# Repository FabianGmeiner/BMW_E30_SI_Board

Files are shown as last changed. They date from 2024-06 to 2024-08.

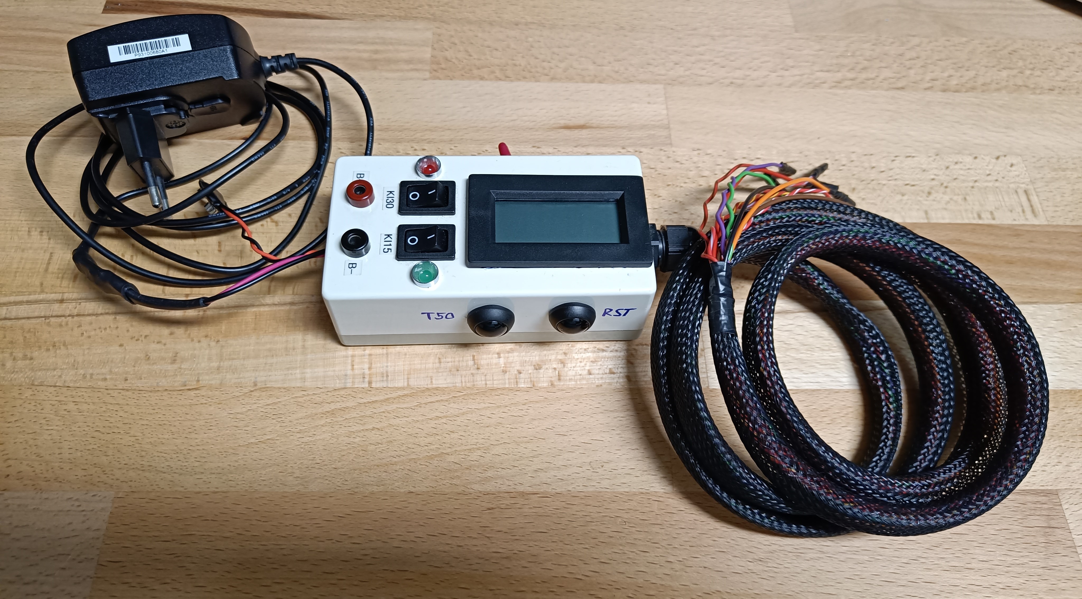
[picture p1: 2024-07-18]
Images/Testing/IMG20240629183347.jpg

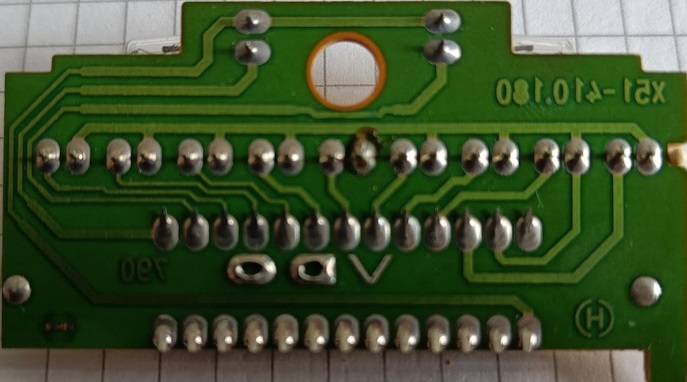
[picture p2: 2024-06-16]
Images/Indicator Rear Crop.jpg

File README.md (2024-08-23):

# About this Project

I'm currently working on a little project for all the early model E30 drivers with SI board trouble from leaky batteries or mechanical damage.

I am reverse engineering the early model SI board, in my case the VDO version (VDO and motometer are interchangeable)

This initial version is a 1:1 copy of the original design. The main microcontroller, the crystal oscillator and the large pin header need to be desoldered and taken over to the new board, but all other components are readily available and stocked parts.

This is mainly to understand the schematics and the workings of the circuit. In a second step I will design my own board with a modern microcontroller and non-volatile storage to work without batteries, with modern and way cheaper components (similar to the board offered by  [ProgRama](https://www.programainc.com/item_detail.aspx?idproduct=177&idcategory=49&sf=)). Also playing with the idea of integrating further functionality, like configurable shift lights on the little indicator board, as all the necessary signals are there anyway.

Warm regards from Germany!

## Current Status

2024/06/24 I received the initial batch of PCBs for testing. This includes the main SI boards as well as the pre-facelift LED board (9 LEDs).

I got all the necessary components from either Mouser or Reichelt (german vendor), but everything is available at Mouser. The [BOM](https://github.com/FabianGmeiner/BMW_E30_SI_Board/blob/main/BOM_SI_Board_Reman.xlsx "BOM_SI_Board_Reman.xlsx") contains all the part descriptions as well as relevant part numbers and the component identification and placement on the second sheet.

The facelift indicator boards (7 LEDs, 3 Bulbs) is based on photographs only, as such I could not yet verify the dimensions apart from measurements from images. 
If anybody has one of those boards laying around and could provide peasurements that would be highly appreciated.

### Testing status

#### Main SI board
**2024/06/24** first board assembled ready for testing.    
**2024/06/30** first functional tests successful. All functions operate as they should, and current consumption is in a nominal range. I am currently building a little pulse generator to test the speed and rpm inputs and test if the oil service lights count down as expected. This will be combined with a long test with the board powered up to check the current consumption and temperatures over longer time. 

| **Test Description** | **Current Draw Board** | **Battery Current** | **Further Comments** |
|---|---|---|---|
| Initial Connection, T30 off, T15 off | | 9.2 µA | Battery current measured between BAT_EN jumper |
| T30 on, T15 off | 3.6 mA | 5.7 µA | All lights stay off, battery current reduces. |
| T30 on, T15 on | 145.9 mA | 5.7 µA | 5 green LEDs turn on, Inspection light turns on |
| Activating T50 (starter signal) | | | Relay clicks, pad indicator lights up |
| Releasing T50 (starter signal) | | | Relay clicks, pad indicator turns off, LEDs turn off |
| Reset Button Pressed | 30.4 mA | | INSP light goes out after ~10s, all lights off |
| T30 on, T15 off | 3.6 mA | | turning ignition off after reset |
| T30 on, T15 on | 89.4 mA | | ignition back on, 5 green LEDs on, INSP light stays off |
| Activating and releasing T50 | 30.5 mA | | Relay cycles, LEDs turn off. All lights off. |
| T30 off, T15 off | | 9.2 µA | |
| Battery charging current | | 22.8 mA | Battery charging with T15 on |
| Battery charging cutoff voltage | | | Board stops charging at a cell voltage of 1.35 V |

The overall functionality, the current consumption as well as the charging current and voltage for the NiMh cells is within the expected range. 

#### Indicator board
**2024/06/24** first board assembled. Electrical test ok. Mechanical fitment is off, the connector header needs to be moved up 2.5mm for the board to sit flush with the main PCB.   
**2024/06/27** PCBs are corrected and updated files uploaded. Ordered a new batch of pre-facelift and facelift boards for testing 
**2024/08/22** noticed during assembly that mounding hole of pre-facelift boards is too small. Needs to be enlarged by 0.5mm -> will be corrected in PCB files
**2024/08/23** updated files for bigger mounting hole

## Schematics

Current versions for the main SI board and the LED indicator board are V2 and can be found as .pdf ([2024_06_15_SI_Board_Schematic_V2.pdf](https://github.com/FabianGmeiner/BMW_E30_SI_Board/blob/main/2024_06_15_SI_Board_Schematic_V2.pdf "2024_06_15_SI_Board_Schematic_V2.pdf"), [2024_06_15_Indicator_Schematic_V2.pdf](https://github.com/FabianGmeiner/BMW_E30_SI_Board/blob/main/2024_06_15_Indicator_Schematic_V2.pdf "2024_06_15_Indicator_Schematic_V2.pdf")) or in the respective KiCad projects.

I also added an LED-only-version of the indicator board, replacing the bulbs with white 5mm LEDs and adding current limiting resistors. The resistors will have to be adapted to the LEDs you are using. 
The same goes for a facelift version of the indicator board, with 7 LEDs (one red) and three bulbs.

The schematics also include the pin assignments and routing of the whole instrument cluster (albeit in german), and should also come in as a handy reference for throubelshooting or repairing an original SI board, e.g. with corroded traces.

## Manufacturing files

Exported Gerbers for getting the boards manufactured are located in the respective KiCad project folders for a variety of different board houses. I ordered mine through JLCPCB. 

## Licensing 
LICENSE NOTE: The root license applies to all subfolders NOT containing their own LICENSE file. If a subfolder contains a different LICENSE file this different license applies to all subfolders below this LICENSE file.

I encourage everyone to get the boards manufactured yourself as the components are cheaply available and its a cool project to keep our old cars running nicely.
If you want to sell any hardware of this project yourself i would kindly ask you to get in contact with me.

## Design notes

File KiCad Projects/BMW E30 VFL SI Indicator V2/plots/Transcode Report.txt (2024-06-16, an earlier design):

   ---- Transcoding 'C:\Users\fabia\OneDrive\Documents\KiCad Projects\BMW E30 VFL SI Indicator\plots\BMW E30 VFL SI Indicator-B_Cu.gbl' ----   Tue Jun  4 21:34:22 2024

D10   --> D144
D11   --> D145
D12   --> D146
D13   --> D147
D14   --> D148
D15   --> D149
D16   --> D150
-----------------------------------------------------------------

   ---- Transcoding 'C:\Users\fabia\OneDrive\Documents\KiCad Projects\BMW E30 VFL SI Indicator\plots\BMW E30 VFL SI Indicator-B_Mask.gbs' ----   Tue Jun  4 21:34:22 2024

D10   --> D151
D11   --> D152
D12   --> D153
D13   --> D154
D14   --> D155
-----------------------------------------------------------------

   ---- Transcoding 'C:\Users\fabia\OneDrive\Documents\KiCad Projects\BMW E30 VFL SI Indicator\plots\BMW E30 VFL SI Indicator-Edge_Cuts.gm1' ----   Tue Jun  4 21:34:22 2024

D10   --> D156
-----------------------------------------------------------------

   ---- Transcoding 'C:\Users\fabia\OneDrive\Documents\KiCad Projects\BMW E30 VFL SI Indicator\plots\BMW E30 VFL SI Indicator-F_Cu.gtl' ----   Tue Jun  4 21:34:22 2024

D10   --> D157
D11   --> D158
D12   --> D159
D13   --> D160
D14   --> D161
D15   --> D162
-----------------------------------------------------------------

   ---- Transcoding 'C:\Users\fabia\OneDrive\Documents\KiCad Projects\BMW E30 VFL SI Indicator\plots\BMW E30 VFL SI Indicator-F_Mask.gts' ----   Tue Jun  4 21:34:22 2024

D10   --> D163
D11   --> D164
D12   --> D165
D13   --> D166
D14   --> D167
-----------------------------------------------------------------

   ---- Transcoding 'C:\Users\fabia\OneDrive\Documents\KiCad Projects\BMW E30 VFL SI Indicator\plots\BMW E30 VFL SI Indicator-F_Silkscreen.gto' ----   Tue Jun  4 21:34:22 2024

D11   --> D168
-----------------------------------------------------------------

   ---- Transcoding 'C:\Users\fabia\OneDrive\Documents\KiCad Projects\BMW E30 VFL SI Indicator\plots\BMW E30 VFL SI Indicator-NPTH.drl' ----   Tue Jun  4 21:34:22 2024

T1   --> T6
-----------------------------------------------------------------

   ---- Transcoding 'C:\Users\fabia\OneDrive\Documents\KiCad Projects\BMW E30 VFL SI Indicator\plots\BMW E30 VFL SI Indicator-NPTH-drl_map.gbr' ----   Tue Jun  4 21:34:22 2024

D10   --> D169
D11   --> D170
D12   --> D171
-----------------------------------------------------------------

   ---- Transcoding 'C:\Users\fabia\OneDrive\Documents\KiCad Projects\BMW E30 VFL SI Indicator\plots\BMW E30 VFL SI Indicator-PTH.drl' ----   Tue Jun  4 21:34:22 2024

T1   --> T7
T2   --> T8
-----------------------------------------------------------------

   ---- Transcoding 'C:\Users\fabia\OneDrive\Documents\KiCad Projects\BMW E30 VFL SI Indicator\plots\BMW E30 VFL SI Indicator-PTH-drl_map.gbr' ----   Tue Jun  4 21:34:22 2024

D10   --> D172
D11   --> D173
D12   --> D174
-----------------------------------------------------------------

   ---- Transcoding 'C:\Users\fabia\OneDrive\Documents\KiCad Projects\BMW E30 VFL SI Indicator\plots\BMW E30 VFL SI Indicator-B_Mask.gbs' ----   Tue Jun  4 21:35:04 2024

D14   --> D100
-----------------------------------------------------------------

   ---- Transcoding 'C:\Users\fabia\OneDrive\Documents\KiCad Projects\BMW E30 VFL SI Indicator\plots\BMW E30 VFL SI Indicator-Edge_Cuts.gm1' ----   Tue Jun  4 21:35:04 2024

D10   --> D101
-----------------------------------------------------------------

   ---- Transcoding 'C:\Users\fabia\OneDrive\Documents\KiCad Projects\BMW E30 VFL SI Indicator\plots\BMW E30 VFL SI Indicator-F_Cu.gtl' ----   Tue Jun  4 21:35:04 2024

D14   --> D102
D15   --> D103
-----------------------------------------------------------------

   ---- Transcoding 'C:\Users\fabia\OneDrive\Documents\KiCad Projects\BMW E30 VFL SI Indicator\plots\BMW E30 VFL SI Indicator-F_Mask.gts' ----   Tue Jun  4 21:35:04 2024

D14   --> D104
-----------------------------------------------------------------

   ---- Transcoding 'C:\Users\fabia\OneDrive\Documents\KiCad Projects\BMW E30 VFL SI Indicator\plots\BMW E30 VFL SI Indicator-F_Silkscreen.gto' ----   Tue Jun  4 21:35:04 2024

D11   --> D105
-----------------------------------------------------------------

   ---- Transcoding 'C:\Users\fabia\OneDrive\Documents\KiCad Projects\BMW E30 VFL SI Indicator\plots\BMW E30 VFL SI Indicator-NPTH-drl_map.gbr' ----   Tue Jun  4 21:35:04 2024

D10   --> D106
D11   --> D107
D12   --> D108
-----------------------------------------------------------------

   ---- Transcoding 'C:\Users\fabia\OneDrive\Documents\KiCad Projects\BMW E30 VFL SI Indicator\plots\BMW E30 VFL SI Indicator-PTH.drl' ----   Tue Jun  4 21:35:04 2024

T1   --> T2
T2   --> T3
-----------------------------------------------------------------

   ---- Transcoding 'C:\Users\fabia\OneDrive\Documents\KiCad Projects\BMW E30 VFL SI Indicator\plots\BMW E30 VFL SI Indicator-PTH-drl_map.gbr' ----   Tue Jun  4 21:35:04 2024

D10   --> D109
D11   --> D110
D12   --> D111
-----------------------------------------------------------------

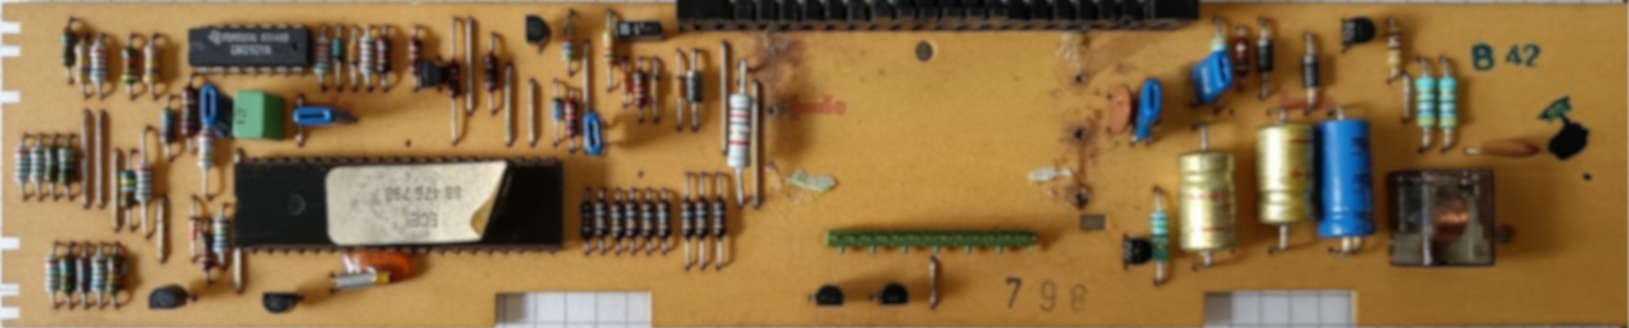
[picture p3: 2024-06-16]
Images/Frontside_Scaled.jpg

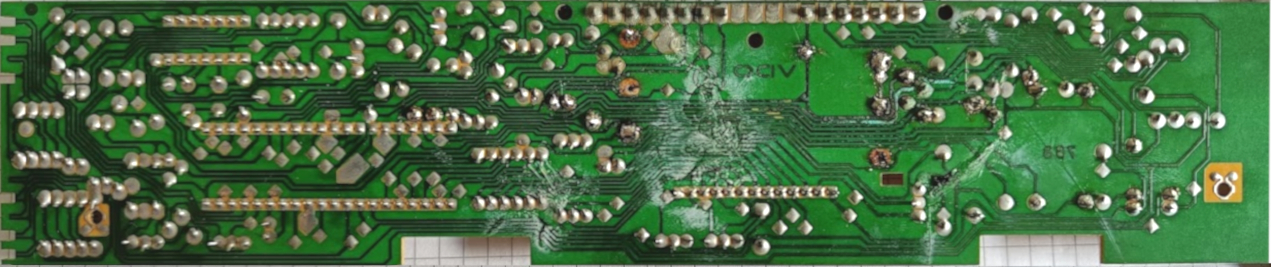
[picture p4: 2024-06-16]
Images/Backside_Scaled.jpg

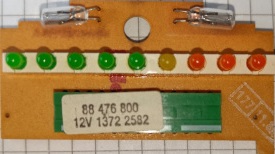
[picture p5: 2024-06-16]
Images/Indicator Front Crop.jpg

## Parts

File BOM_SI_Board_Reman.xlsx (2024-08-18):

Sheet: BOM_V1+V2
 |  |  |  |  |  |  |  |  | SUMME Mouser |  |  | SUMME Reichelt
 |  |  |  |  |  |  |  |  | 6.47 € |  |  | 4.05 €
 | Sum of Qty: | 102
Item # | *Designator | *Qty | Qty. for 10 boards | Description / Value | *Package/Footprint | Type | Your Instructions / Notes | Mouser Nr. | Mouser Unit Price | Mouser Total Price | Reichelt Nr. | Reichelt Unit Price | Reichelt Total Price
1 | R1 | 1 | 10 | 825 Ohms 2% 1/4W | THT |  |  |  |  |  | METALL 825 | 0.035 | 0.035
2 | R2 | 1 | 10 | 1.65k Ohms 1% 1/4W | THT |  |  |  |  |  | METALL 1,65K | 0.035 | 0.035
3 | R3 | 1 | 10 | 3.32k Ohms 2% 50ppm 1/4W | THT |  |  |  |  |  | METALL 3,32K | 0.035 | 0.035
4 | R4 | 1 | 10 | 6.65k Ohms 1% 1/4W | THT |  |  |  |  |  | METALL 6,65K | 0.035 | 0.035
5 | R5 | 1 | 10 | 13.3k Ohms 2% 1/4W | THT |  |  |  |  |  | METALL 13,3K | 0.035 | 0.035
6 | R6 | 1 | 10 | 7.15k Ohms 2% 1/4W | THT |  |  |  |  |  | METALL 7,15K | 0.035 | 0.035
7 | R7 | 1 | 10 | 3.57k Ohms 1% 1/4W | THT |  |  |  |  |  | METALL 3,57K | 0.06 | 0.06
8 | R8 | 1 | 10 | 1.78k Ohms 1% 1/4W | THT |  |  |  |  |  | METALL 1,78K | 0.035 | 0.035
9 | R9 | 1 | 10 | 887 Ohms 1% 1/4W | THT |  |  |  |  |  | METALL 887 | 0.035 | 0.035
10 | R10 | 1 | 10 | 64.9k Ohms 2% 1/4W | THT |  |  |  |  |  | METALL 64,9K | 0.035 | 0.035
11 | R11, R39 | 2 | 10 | 1k Ohms 2% 1/4W | THT |  |  |  |  |  | METALL 1,00K | 0.035 | 0.07
12 | R12 | 1 | 10 | 35.7k Ohms 1% 1/4W | THT |  |  |  |  |  | METALL 35,7K | 0.05 | 0.05
13 | R13, R16 | 2 | 10 | 470k Ohms 5% 1/4W | THT |  |  |  |  |  | METALL 470K | 0.035 | 0.07
14 | R14 | 1 | 10 | 16.2k Ohms 2% 1/4W | THT |  |  |  |  |  | METALL 16,2K | 0.035 | 0.035
15 | R15 | 1 | 10 | 43.2k Ohms 1% 1/4W | THT |  |  |  |  |  | METALL 43,2K | 0.035 | 0.035
16 | R17 | 1 | 10 | 4.75k Ohms 2% 50ppm 1/4W | THT |  |  |  |  |  | METALL 4,75K | 0.035 | 0.035
17 | R18 | 1 | 10 | 750 Ohms 5% 1/2W | THT |  |  | MF1/2CCT52R7500F | 0.406 | 0.406
18 | R19, R40 | 2 | 10 | 51k Ohms 5% 1/4W | THT |  |  |  |  |  | METALL 51,0K | 0.035 | 0.07
19 | R20 | 1 | 10 | 24.9k Ohms 2% 1/4W | THT |  |  |  |  |  | METALL 24,9K | 0.035 | 0.035
20 | R21 | 1 | 10 | 66.5 Ohms 1% 1/4W | THT |  |  |  |  |  | METALL 66,5 | 0.08 | 0.08
21 | R22 | 1 | 10 | 56.2k Ohms 2% 1/4W | THT |  |  |  |  |  | METALL 56,2K | 0.035 | 0.035
22 | R23 | 1 | 10 | 12.1k Ohms 1% 1/4W | THT |  |  |  |  |  | METALL 12,1K | 0.035 | 0.035
23 | R24 | 1 | 10 | 2.7k Ohms 5% 1/4W | THT |  |  |  |  |  | METALL 2,70K | 0.035 | 0.035
24 | R25 | 1 | 10 | 10k Ohms 5% 1/4W | THT |  |  |  |  |  | METALL 10,0K | 0.035 | 0.035
25 | R26, R28 | 2 | 10 | 16k Ohms 5% 1/4W | THT |  |  |  |  |  | METALL 16,0K | 0.035 | 0.07
26 | R27 | 1 | 10 | 75 Ohms 10% 1/4W | THT |  |  |  |  |  | METALL 75,0 | 0.035 | 0.035
27 | R29 | 1 | 10 | 5.6k Ohms 5% 1/4W | THT |  |  |  |  |  | METALL 5,60K | 0.035 | 0.035
28 | R30 - R38 | 9 | 45 | 160 Ohms 5% 1/4W | THT |  |  |  |  |  | METALL 160 | 0.035 | 0.315
29 | R41 | 1 | 10 | 12 Ohms 2% 1W | THT |  |  |  |  |  | VI MBE04140C1209 | 0.17 | 0.17
30 | R42 | 1 | 10 | 75 Ohms 5% 1/2W | THT |  |  | MF1/2DCT52R75R0F | 0.392 | 0.392
31 | R43 | 1 | 10 | 1.3k Ohms 5% 1/4W | THT |  |  |  |  |  | METALL 1,30K | 0.035 | 0.035
32 | R44 | 1 | 10 | 390 Ohms 5% 1/2W | THT |  |  | MF1/2DCT52R3900F | 0.392 | 0.392
33 | R45 | 1 | 10 | 4.7k Ohms 5% 1/4W | THT |  |  |  |  |  | METALL 4,70K | 0.035 | 0.035
34 | R46 | 1 | 10 | 10 Ohms 5% 1/4W | THT |  |  |  |  |  | METALL 10,0 | 0.035 | 0.035
35 | R47, R48 | 2 | 10 | 470 Ohms 5% 1/2W | THT |  |  | MF1/2DCT52R4700F | 0.229 | 0.458
36 | R100 - R113 | 13 | 130 | 0 Ohm wire bridge | THT |  | DNP
37 | D1, D3, D5, D11 | 4 | 20 | 1N4148 | DO-35 |  |  | 512-1N4148 | 0.053 | 0.212
38 | D2 | 1 | 10 | BZX 55C 6V2 500mW | DO-35 |  |  | 78-BZX55C6V2-TAP | 0.101 | 0.101
39 | D4 | 1 | 10 | BZX 55C 5V1 500mW | DO-35 |  |  | 78-BZX55C5V1 | 0.102 | 0.102
40 | D6, D7 | 2 | 10 | BAV21 250mW | DO-35 |  |  |  |  |  | BAV 21 | 0.04 | 0.08
41 | D8, D9, D10 | 3 | 15 | 1N4005G | DO-41 |  |  | 863-1N4005RLG | 0.073 | 0.219
42 | C1, C3, C4, C7, C8 | 5 | 25 | 100nF +50/-20% >=63V | THT, LS=5.08mm | Ceramic MLCC |  | 81-RCER72A104K1M1H3A | 0.179 | 0.895
43 | C2 | 1 | 5 | 470nF 10% 63V MKT1817 | THT, LS=5.08mm | Film |  | MKT1817447065 | 0.755 | 0.755
44 | C5 | 1 | 5 | 100nF 20% 63V MKT1817 | THT, LS=5.08mm | Film |  | MKT1817410065 | 0.429 | 0.429
45 | C6, C12 | 2 | 10 | 4,7nF 10% 1000V | THT, LS=5 / 5.08mm | Ceramic MLCC | RDER73A473K4M1H03A |  |  |  | KERKO-500 4,7N | 0.05 | 0.1
46 | C9, C10 | 2 | 10 | 100µF 20% 16V 85°C | Axial, D < 8,5mm, L< 18mm | Elco | MAL213825101E3 |  |  |  | AX 105 100/16 | 0.43 | 0.86
47 | C11 | 1 | 5 | 100µF 20% 63V 85°C | Axial, D < 8,5mm, L< 18mm | Elco | MAL202138101E3 |  |  |  | COS 105 100/63 | 0.49 | 0.49
48 | Q1, Q4 | 2 | 10 | BC547C 100mA 45V | TO-92 Kinked Lead |  | original: BC237C obsolete |  |  |  | BC 547C | 0.05 | 0.1
49 | Q2 | 1 | 10 | BC557B 100mA 45V | TO-92 Kinked Lead |  | original: BC307B obsolete |  |  |  | BC 557B | 0.05 | 0.05
50 | Q3, Q5, Q6, Q7 | 4 | 20 | BC337-25 800mA 45V | TO-92 Kinked Lead |  |  |  |  |  | BC 337-25 | 0.06 | 0.24
51 | Q8 | 1 | 10 | BC327-16 800mA 45V | TO-92 Kinked Lead |  |  |  |  |  | BC 327-16 | 0.06 | 0.06
52 | K1 | 1 | 10 | SR7-9V-200-1C | THT |  | original: MZ-9HS-C, alternative HKE HRS1KH-S-DC9V, TE OUAZ-SS-109L,900 | 179-SR7-9V-200-1C | 1.01 | 1.01
53 | Y1 | 1 | 10 |  |  |  | no markings |  |  | 0
54 | U1 | 1 | 10 | TE 1-2199299-5 or Amphenol DILB40P-223TLF | DIP-40 |  | take over from original PCB | 571-1-2199299-5 | 0.645 | 0.645
55 | U2 | 1 | 10 | LM2901N | PDIP-14 |  |  | 595-LM2901N | 0.45 | 0.45
56 | BT1, BT2 | 2 | 20 | NiCd Batteries |  |  | https://www.timsclassicparts.nl/de_DE/a-63630636/tacho-zahnradsatz/e30-si-board-akku-grosses-modell/
57 | J1 | 1 | 10 | 19 Pin 3mm Pitch Molded Frame 90° |  |  | take over from original PCB
58 | J2 | 1 | 10 | 13 Pin standard 2,54mm pitch pin header |  |  |  |  |  |  | SL 1X40G 2,54 | 0.27 | 0.27
59 | J3 | 1 | 10 | 2 Pin standard 2,54 pitch pin header |  |  |  |  |  |  | MPE 087-1-002 | 0.06 | 0.06
60 | J4 | 1 | 10 | 2 pin standard 2,54 pitch jumper |  |  |  |  |  |  | JUMPER 2,54 SW | 0.02 | 0.02

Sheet: BOM_V3
 |  |  |  |  |  | Changes compared to V1/V2
 |  |  |  |  |  |  |  |  |  | SUMME Mouser |  |  | SUMME Reichelt
 |  |  |  |  |  |  |  |  |  | 26.00 € |  |  | 4.23 €
 | Sum of Qty: | 91
Item # | *Designator | *Qty | Qty. for 10 boards | Description / Value | *Package/Footprint | Type | Your Instructions / Notes | Pitch [mm] | Mouser Nr. | Mouser Unit Price | Mouser Total Price | Reichelt Nr. | Reichelt Unit Price | Reichelt Total Price
1 | R1 | 1 | 10 | 825 Ohms 2% 1/4W | THT |  |  | 10.16 | 603-MF0207FTE52-825R | 0.112 | 0.112 | METALL 825 | 0.035 | 0.035
2 | R2 | 1 | 10 | 1.65k Ohms 1% 1/4W | THT |  |  | 10.16 | 603-MFR-25FBF52-1K65 | 0.093 | 0.093 | METALL 1,65K | 0.035 | 0.035
3 | R3 | 1 | 10 | 3.32k Ohms 2% 50ppm 1/4W | THT |  |  | 10.16 | 603-MF0207FRE52-3K32 | 0.093 | 0.093 | METALL 3,32K | 0.035 | 0.035
4 | R4 | 1 | 10 | 6.65k Ohms 1% 1/4W | THT |  |  | 10.16 | 603-MF0207FTE52-6K65 | 0.112 | 0.112 | METALL 6,65K | 0.035 | 0.035
5 | R5 | 1 | 10 | 13.3k Ohms 2% 1/4W | THT |  |  | 10.16 | 603-MF0207FTE52-13K3 | 0.112 | 0.112 | METALL 13,3K | 0.035 | 0.035
6 | R6 | 1 | 10 | 7.15k Ohms 2% 1/4W | THT |  |  | 10.16 | 603-MFR-25FRF52-7K15 | 0.093 | 0.093 | METALL 7,15K | 0.035 | 0.035
7 | R7 | 1 | 10 | 3.57k Ohms 1% 1/4W | THT |  |  | 10.16 | 603-MF0207FTE52-3K57 | 0.112 | 0.112 | METALL 3,57K | 0.06 | 0.06
8 | R8 | 1 | 10 | 1.78k Ohms 1% 1/4W | THT |  |  | 10.16 | 603-MFR-25FBF52-1K78 | 0.093 | 0.093 | METALL 1,78K | 0.035 | 0.035
9 | R9 | 1 | 10 | 887 Ohms 1% 1/4W | THT |  |  | 10.16 | 603-MF0207FTE52-887R | 0.112 | 0.112 | METALL 887 | 0.035 | 0.035
10 | R10 | 1 | 10 | 64.9k Ohms 2% 1/4W | THT |  |  | 12.7 | 603-MF0207FTE52-64K9 | 0.112 | 0.112 | METALL 64,9K | 0.035 | 0.035
11 | R11, R39 | 2 | 10 | 1k Ohms 2% 1/4W | THT |  |  | 17,78 / 12,7 | 603-MF0207FRE52-1K | 0.093 | 0.186 | METALL 1,00K | 0.035 | 0.07
12 | R12 | 1 | 10 | 35.7k Ohms 1% 1/4W | THT |  |  | 10.16 | 603-MF0207FTE52-35K7 | 0.112 | 0.112 | METALL 35,7K | 0.05 | 0.05
13 | R13, R16 | 2 | 10 | 470k Ohms 5% 1/4W | THT |  |  | 10.16 | 603-MF0207FRE52-470K | 0.093 | 0.186 | METALL 470K | 0.035 | 0.07
14 | R14 | 1 | 10 | 16.2k Ohms 2% 1/4W | THT |  |  | 10.16 | 603-MF0207FTE52-16K2 | 0.112 | 0.112 | METALL 16,2K | 0.035 | 0.035
15 | R15 | 1 | 10 | 43.2k Ohms 1% 1/4W | THT |  |  | 10.16 | 603-MF0207FTE52-43K2 | 0.112 | 0.112 | METALL 43,2K | 0.035 | 0.035
16 | R17 | 1 | 10 | 4.75k Ohms 2% 50ppm 1/4W | THT |  |  | 10.16 | 603-MF0207FRE52-4K75 | 0.093 | 0.093 | METALL 4,75K | 0.035 | 0.035
17 | R18 | 1 | 10 | 750 Ohms 5% 1/2W | THT |  |  | 12.7 | MF1/2CCT52R7500F | 0.406 | 0.406
18 | R19, R40 | 2 | 10 | 51k Ohms 5% 1/4W | THT |  |  | 10.16 | 603-MF0207FTE52-51K | 0.112 | 0.224 | METALL 51,0K | 0.035 | 0.07
19 | R20 | 1 | 10 | 24.9k Ohms 2% 1/4W | THT |  |  | 15.24 | 603-MF0207FTE52-24K9 | 0.093 | 0.093 | METALL 24,9K | 0.035 | 0.035
20 | R21 | 1 | 10 | 100 Ohms 5% 1/4W | THT |  |  | 10.16 | 603-MF0207FRE52-100R | 0.093 | 0.093 | METALL 100 | 0.035 | 0.035
21 | R22 | 1 | 10 | 56.2k Ohms 2% 1/4W | THT |  |  | 10.16 | 603-MF0207FTE52-56K2 | 0.112 | 0.112 | METALL 56,2K | 0.035 | 0.035
22 | R23 | 1 | 10 | 12.1k Ohms 1% 1/4W | THT |  |  | 10.16 | 603-MF0207FTE52-12K1 | 0.112 | 0.112 | METALL 12,1K | 0.035 | 0.035
23 | R24 | 1 | 10 | 2.7k Ohms 5% 1/4W | THT |  |  | 10.16 | 603-MF0207FRE52-2K7 | 0.093 | 0.093 | METALL 2,70K | 0.035 | 0.035
24 | R25 | 1 | 10 | 10k Ohms 5% 1/4W | THT |  |  | 10.16 | 603-MF0207FRE52-10K | 0.093 | 0.093 | METALL 10,0K | 0.035 | 0.035
25 | R26, R28 | 2 | 10 | 16k Ohms 5% 1/4W | THT |  |  | 20,32 / 10,16 | 603-MF0207FTE52-16K | 0.112 | 0.224 | METALL 16,0K | 0.035 | 0.07
26 | R27 | 1 | 10 | 75 Ohms 10% 1/4W | THT |  |  | 12.7 | 603-MF0207FTE52-75R | 0.112 | 0.112 | METALL 75,0 | 0.035 | 0.035
27 | R29 | 1 | 10 | 5.6k Ohms 5% 1/4W | THT |  |  | 10.16 | 603-MF0207FTE52-5K6 | 0.093 | 0.093 | METALL 5,60K | 0.035 | 0.035
28 | R30 - R38 | 9 | 45 | 160 Ohms 5% 1/4W | THT |  |  | 10,16 / 15,24 | 603-MFR50SFTE52-160R | 0.102 | 0.918 | METALL 160 | 0.035 | 0.315
29 | R41 | 1 | 10 | 12 Ohms 2% 1W | THT |  |  | 22.86 | MBE04140C1209DC100 | 0.595 | 0.595 | VI MBE04140C1209 | 0.17 | 0.17
30 | R42 | 1 | 10 | 75 Ohms 5% 1/2W | THT |  |  | 15.24 | MF1/2DCT52R75R0F | 0.392 | 0.392
31 | R43 | 1 | 10 | 1.3k Ohms 5% 1/4W | THT |  |  | 10.16 | 603-MF0207FTE52-1K3 | 0.112 | 0.112 | METALL 1,30K | 0.035 | 0.035
32 | R44 | 1 | 10 | 390 Ohms 5% 1/2W | THT |  |  | 15.24 | MF1/2DCT52R3900F | 0.392 | 0.392
33 | R45 | 1 | 10 | 4.7k Ohms 5% 1/4W | THT |  |  | 10.16 | 603-MF0207FRE52-4K7 | 0.093 | 0.093 | METALL 4,70K | 0.035 | 0.035
34 | R46 | 1 | 10 | 10 Ohms 5% 1/4W | THT |  |  | 10.16 | 603-MF0207FTE26-10R | 0.093 | 0.093 | METALL 10,0 | 0.035 | 0.035
35 | R47, R48 | 2 | 10 | 470 Ohms 5% 1/2W | THT |  |  | 15.24 | MF1/2DCT52R4700F | 0.229 | 0.458
37 | D1, D3, D5, D11 | 4 | 20 | 1N4148 | DO-35 |  |  | 10,16 / 10,16 / 7,62 / 10,16 | 512-1N4148 | 0.053 | 0.212
38 | D2 | 1 | 10 | BZX 55C 6V2 500mW | DO-35 |  |  | 10.16 | 78-BZX55C6V2-TAP | 0.101 | 0.101
39 | D4 | 1 | 10 | BZX 55C 5V1 500mW | DO-35 |  |  | 10.16 | 78-BZX55C5V1 | 0.102 | 0.102
40 | D6, D7 | 2 | 10 | BAV-21 | DO-35 |  |  | 10,16 / 12,7 | 637-BAV21 | 0.102 | 0.204 | BAV 21 | 0.04 | 0.08
41 | D8, D9, D10 | 3 | 15 | 1N4005G | DO-41 |  |  | 12.7 | 863-1N4005RLG | 0.073 | 0.219
42 | C1, C3, C4, C7, C8 | 5 | 25 | 100nF +50/-20% >=63V | THT, LS=5.08mm | Ceramic MLCC |  | 5.08 | 81-RCER72A104K1M1H3A | 0.179 | 0.895
43 | C2 | 1 | 5 | 470nF 10% 63V MKT1817 | THT, LS=5.08mm | Film |  | 5.08 | MKT1817447065 | 0.755 | 0.755
44 | C5 | 1 | 5 | 100nF 20% 63V MKT1817 | THT, LS=5.08mm | Film |  | 5.08 | MKT1817410065 | 0.429 | 0.429
45 | C6, C12 | 2 | 10 | 4,7nF 10% 1000V | THT, LS=5 / 5.08mm | Ceramic MLCC | RDER73A473K4M1H03A | 5.08 | 81-RDER73A473K4M1H3A | 1.03 | 2.06 | KERKO-500 4,7N | 0.05 | 0.1
46 | C9, C10 | 2 | 10 | 100µF 20% 16V 85°C | Axial, D < 8,5mm, L< 18mm | Elco | MAL213825101E3 | 22.86 | 594-2222-138-35101 | 2.88 | 5.76 | AX 105 100/16 | 0.43 | 0.86
47 | C11 | 1 | 5 | 100µF 20% 63V 85°C | Axial, D < 8,5mm, L< 18mm | Elco | MAL202138101E3 | 22.86 | 594-2222-138-21101 | 2.95 | 2.95 | COS 105 100/63 | 0.49 | 0.49
48 | Q1, Q4 | 2 | 10 | BC547C 100mA 45V | TO-92 Kinked Lead |  | original: BC237C obsolete |  | 637-BC547C | 0.093 | 0.186 | BC 547C | 0.05 | 0.1
50 | Q3, Q5, Q6, Q7 | 4 | 20 | BC337-25 800mA 45V | TO-92 Kinked Lead |  |  |  | 637-BC337-25 | 0.13 | 0.52 | BC 337-25 | 0.06 | 0.24
51 | Q8 | 1 | 10 | BC327-16 800mA 45V | TO-92 Kinked Lead |  |  |  | 637-BC327-16 | 0.13 | 0.13 | BC 327-16 | 0.06 | 0.06
52 | K1 | 1 | 10 | SR7-9V-200-1C | THT |  | original: MZ-9HS-C, alternative HKE HRS1KH-S-DC9V, TE OUAZ-SS-109L,900 |  | 179-SR7-9V-200-1C | 1.01 | 1.01
53 | Y1 | 1 | 10 |  |  |  | take over from original PCB
54 | U1 | 1 | 10 | TE 1-2199299-5 or Amphenol DILB40P-223TLF | DIP-40 |  | take over from original PCB |  | 571-1-2199299-5 | 0.645 | 0.645
55 | U2 | 1 | 10 | LM2901N | PDIP-14 |  |  |  | 595-LM2901N | 0.45 | 0.45
56 | BT1, BT2 | 2 | 20 | Keystone 54 CR123 battery holder |  |  |  |  | 534-54 | 0.623 | 1.246
57 | J1 | 1 | 10 | 19 Pin 3mm Pitch Molded Frame 90° |  |  | take over from original PCB
58 | J2 | 1 | 10 | 13 Pin standard 2,54mm pitch pin header |  |  |  |  | 710-61301311121 | 0.698 | 0.698 | SL 1X40G 2,54 | 0.27 | 0.27
59 | J3 | 1 | 10 | 3 Pin standard 2,54 pitch pin header |  |  |  |  | 649-1012937890304BLF | 0.102 | 0.102 | MPE 087-1-003 | 0.07 | 0.07
61 | D12 | 1 | 10 | BAT46 | DO-35 |  |  | 7.62 | 511-BAT46 | 0.298 | 0.298 | BAT 46 | 0.05 | 0.05
62 | D13 | 1 | 10 | Green LED, 3mm | 3mm LED THT |  |  |  | 710-151031VS06000 | 0.158 | 0.158 | LED 3MM GN | 0.07 | 0.07
63 | C13, C15 | 2 | 20 | 1nF ceramic cap, 5mm pitch THT | THT, LS=5mm |  |  | 5.08 | 594-K102K15X7RH5TH5 | 0.158 | 0.316 | X7R-5 1,0N | 0.08 | 0.16

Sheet: Component Labeling
7.62
10.16
12.7
15.24
17.78
20.32
22.86
25.4

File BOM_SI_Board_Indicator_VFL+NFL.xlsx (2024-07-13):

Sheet: BOM VFL Indicator
 |  |  |  |  |  |  |  | SUMME Reichelt
 |  |  |  |  |  |  |  | 0.99 €
 | Sum of Qty: | 15
Item # | *Designator | *Qty | Description / Value | *Package/Footprint | Type | Reichelt Nr. | Reichelt Unit Price | Reichelt Total Price
1 | PCB | 1 | Manufacturing Files on Github (https://github.com/FabianGmeiner/BMW_E30_SI_Board/tree/main/KiCad%20Projects/BMW%20E30%20VFL%20SI%20Indicator%20LED/gerber_to_order) |  | Custom |  |  | 0
2 | LED Holder | 1 | 3D Files on Github (https://github.com/FabianGmeiner/BMW_E30_SI_Board/blob/main/CAD/LED_Holder_VFL.stp) |  | Custom |  |  | 0
3 | D1-D3 | 3 | Red LED, 3mm, 50mA | 3mm THT |  | LED 3MM RT | 0.07 | 0.21
4 | D4 | 1 | Yellow LED, 3mm, 50mA | 3mm THT |  | LED 3MM GE | 0.07 | 0.07
5 | D5-D9 | 5 | Green LED, 3mm, 50mA | 3mm THT |  | LED 3MM GN | 0.07 | 0.35
6 | D10, D11 | 2 | White LED, rectangular 2x5mm, 250mcd, 20mA | rectangular 2x5mm THT |  | 2534W2D-KHA-A | 0.11 | 0.22
7 | R1, R2 | 2 | 510 Ohms 5% 1/4W | THT |  | METALL 510 | 0.07 | 0.14

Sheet: BOM NFL Indicator
 |  |  |  |  |  |  |  | SUMME Reichelt
 |  |  |  |  |  |  |  | 1.02 €
 | Sum of Qty: | 15
Item # | *Designator | *Qty | Description / Value | *Package/Footprint | Type | Reichelt Nr. | Reichelt Unit Price | Reichelt Total Price
1 | PCB | 1 | Manufacturing Files on Github (https://github.com/FabianGmeiner/BMW_E30_SI_Board/tree/main/KiCad%20Projects/BMW%20E30%20NFL%20SI%20Indicator%20LED/gerber_to_order) |  | Custom
2 | LED Holder | 1 | 3D Files on Github (https://github.com/FabianGmeiner/BMW_E30_SI_Board/blob/main/CAD/LED_Holder_NFL.stp) |  | Custom
3 | D1 | 1 | Red LED, 3mm, 50mA | 3mm THT |  | LED 3MM RT | 0.07 | 0.07
4 | D2 | 1 | Yellow LED, 3mm, 50mA | 3mm THT |  | LED 3MM GE | 0.07 | 0.07
5 | D3-D7 | 5 | Green LED, 3mm, 50mA | 3mm THT |  | LED 3MM GN | 0.07 | 0.35
6 | D10, D12 | 2 | White LED, rectangular 2x5mm, 250mcd, 20mA | rectangular 2x5mm THT |  | 2534W2D-KHA-A | 0.11 | 0.22
7 | D11 | 1 | White LED, 3mm, 20mA | 3mm THT |  | 3034W2D-EHD-A | 0.10 | 0.10
8 | R1-R3 | 3 | 510 Ohms 5% 1/4W | THT |  | METALL 510 | 0.07 | 0.21

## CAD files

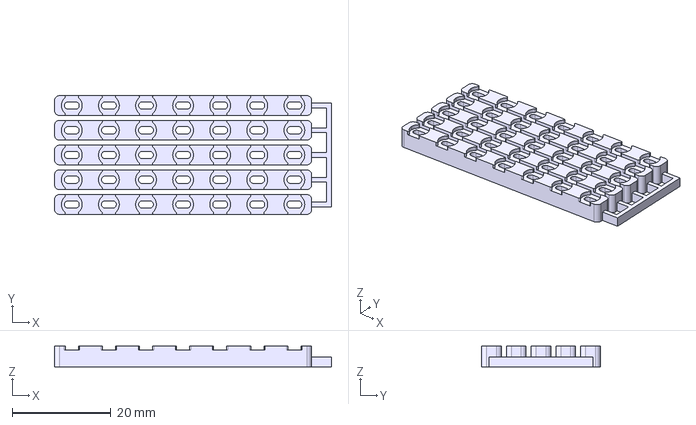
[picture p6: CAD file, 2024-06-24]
CAD/LED_Holder_NFL.stp
56.0 x 24.0 x 4.20 mm

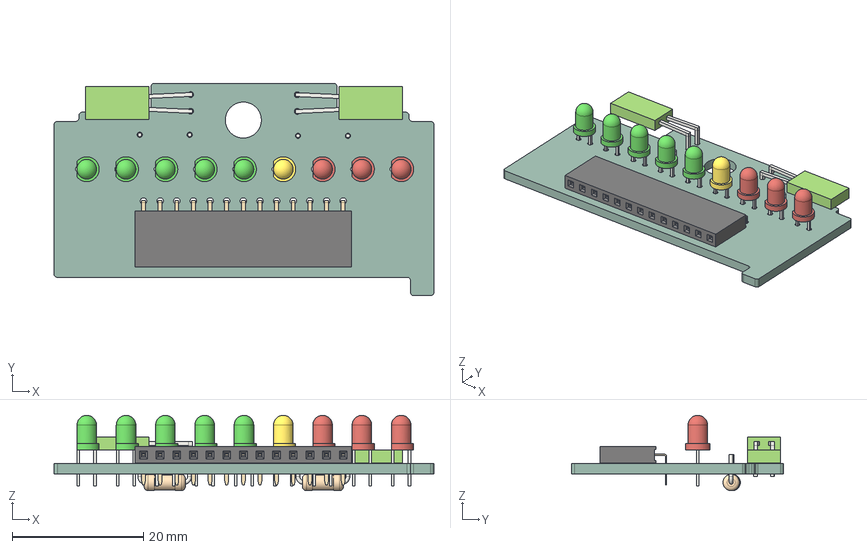
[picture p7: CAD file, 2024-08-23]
KiCad Projects/BMW E30 VFL SI Indicator LED/BMW_E30_VFL_SI_Indicator_LED.step
58.0 x 32.4 x 11.5 mm
LED_D3.0mm x 9
LED_Rectangular_W5.0mm_H2.0mm_Horizontal_O6.35mm_Z3.0mm
LED_Rectangular_W5.0mm_H2.0mm_Horizontal_O6.35mm_Z1.0mm
PinSocket_1x13_P254mm_Horizontal
R_Axial_DIN0207_L63mm_D25mm_P762mm_Horizontal x 2
BMW_E30_VFL_SI_Indicator_LED_PCB

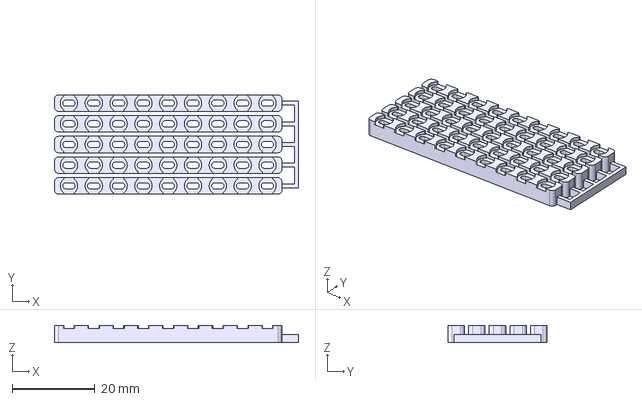
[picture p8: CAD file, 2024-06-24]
CAD/LED_Holder_VFL.stp
59.0 x 24.0 x 4.20 mm

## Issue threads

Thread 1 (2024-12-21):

Request for Information on Power Supply in Testing Images

Anton1001001, 2024-12-21:
Hi Fabian,

I hope you're doing well! I am currently a student working on developing electronic PCBs, and I have a particular interest in classic German cars, especially BMW E30. I noticed the power supply featured in the BMW_E30_SI_Board\Images\Testing folder, and I was wondering if you could tell me the name or model of that power supply?

I would really appreciate your help, and I’m excited to learn more about your work in this area.

Best regards,
Anton

FabianGmeiner, 2024-12-22:
Hi Anton,

the power supply box you can see on the images is a pretty rudimentary perfboard job on the inside.
The main power supply is a generic AC to 24V DC Power supply i had lying around.

I then used two of these small adjustable DCDC boards (something like this: https://www.amazon.de/Heevhas-Spannungsregler-Step-Down-Leistungswandlermodul-Einstellbare-Stromversorgungsmodul/dp/B0CW9MGLZ2/) for the 12V and 5V supplies.

On the 12V side, I added two switches to be able to supply the T30 and T15 pin separately. I also added a small ampmeter (something like this: https://www.conrad.de/de/p/voltcraft-dvm210-digitales-einbaumessgeraet-199-9-mv-beliebig-erweiterbar-durch-vorschalten-von-widerstaenden-126596.html) in the 12V path to monitor the current consumption.

I also added a button to switch the reset input pin to 5V to reset the board, and a button to switch T50 (starter signal) to 12V to test if the lights go out correctly after starting the car.

Since I just threw all that together I dont have any schematics or similar, but I hope the description helps

Anton1001001, 2024-12-25:
Thank you so much for your detailed explanation and the links! This is really helpful. I'll take some time to go through everything and try to assemble the power supply myself. Your description has given me a much better understanding of how to approach it.

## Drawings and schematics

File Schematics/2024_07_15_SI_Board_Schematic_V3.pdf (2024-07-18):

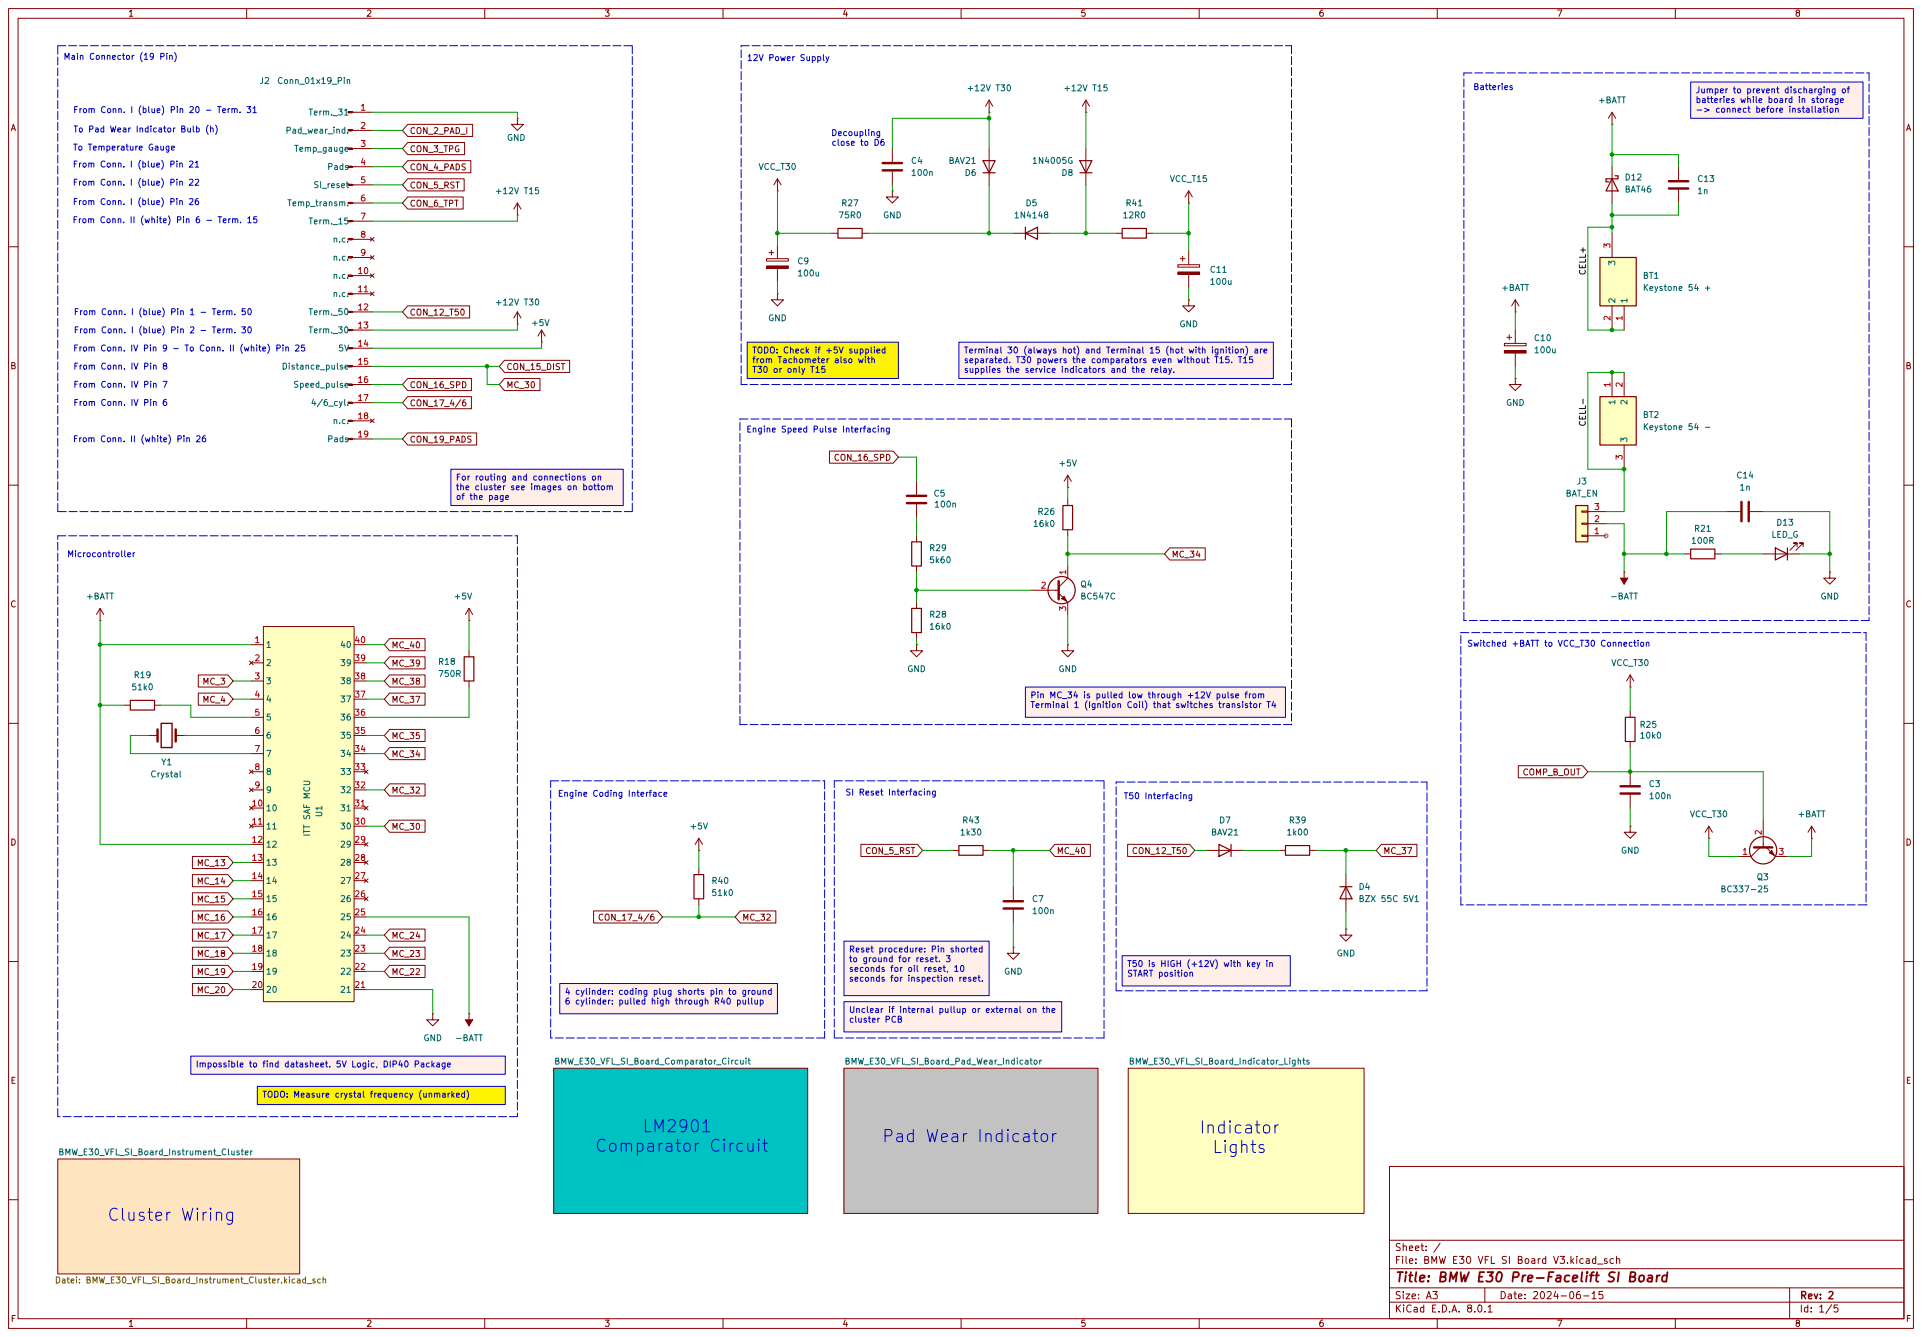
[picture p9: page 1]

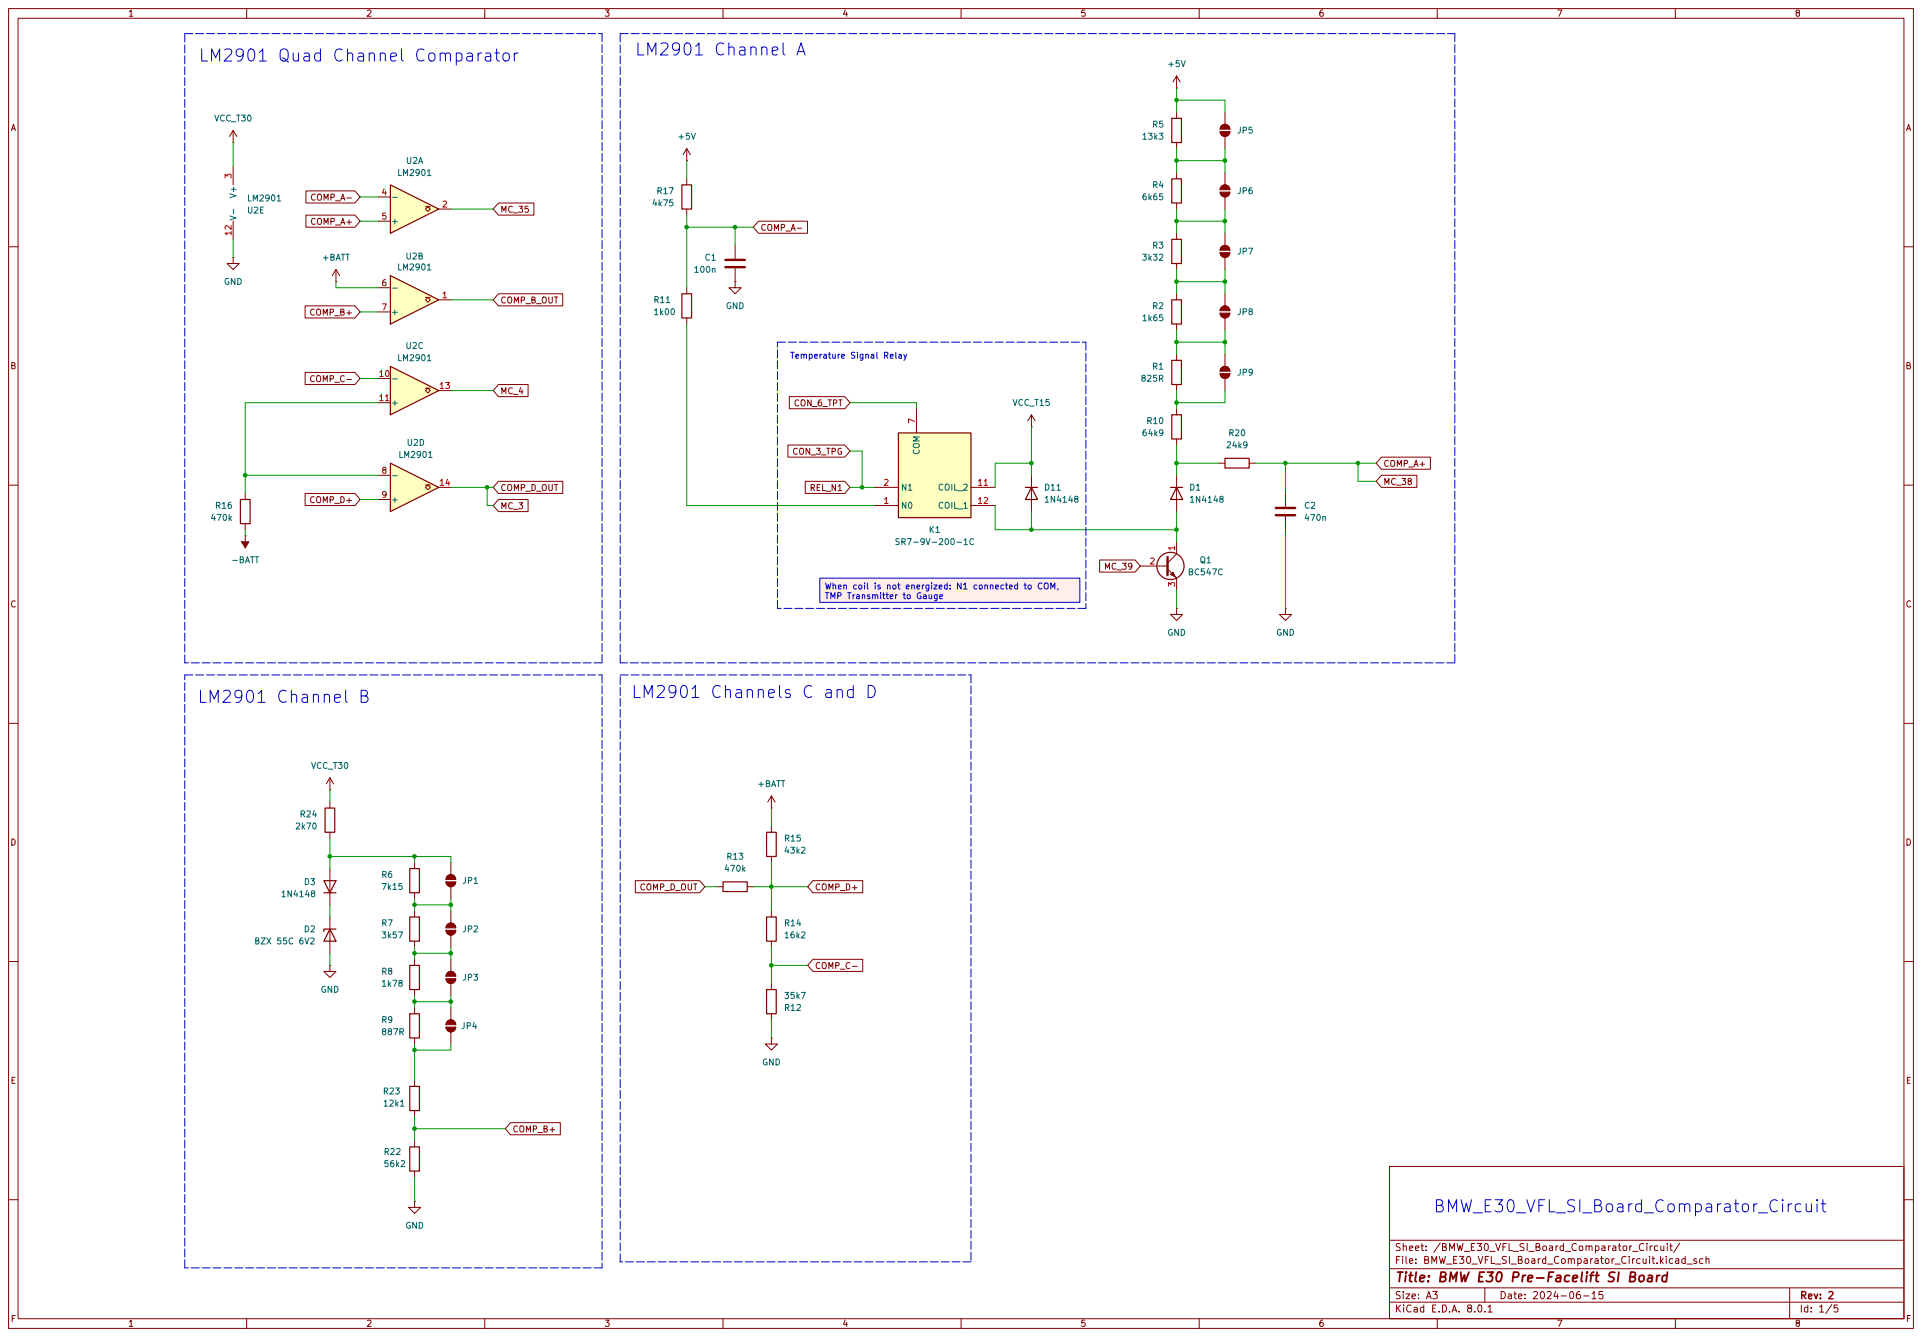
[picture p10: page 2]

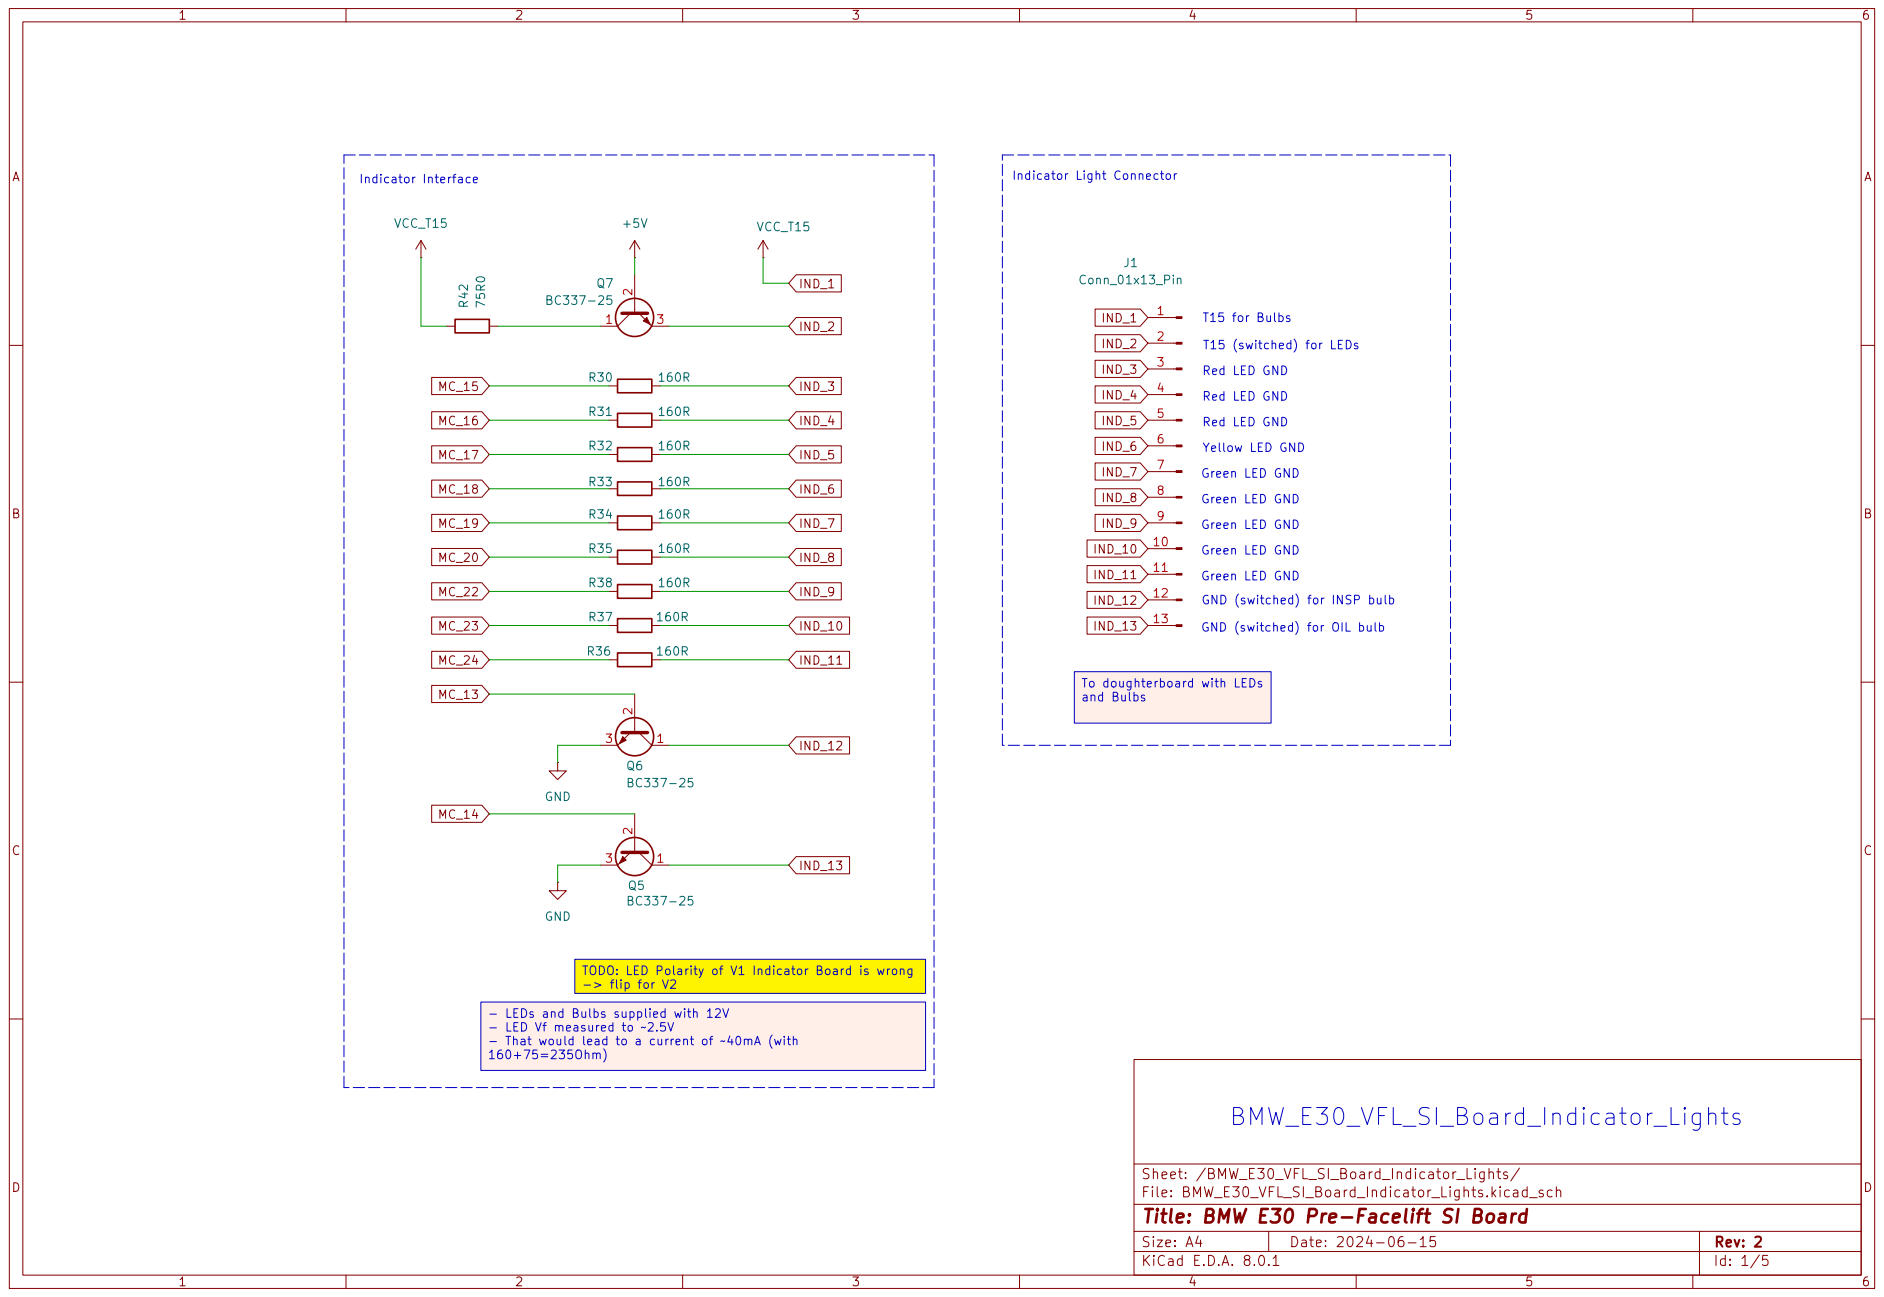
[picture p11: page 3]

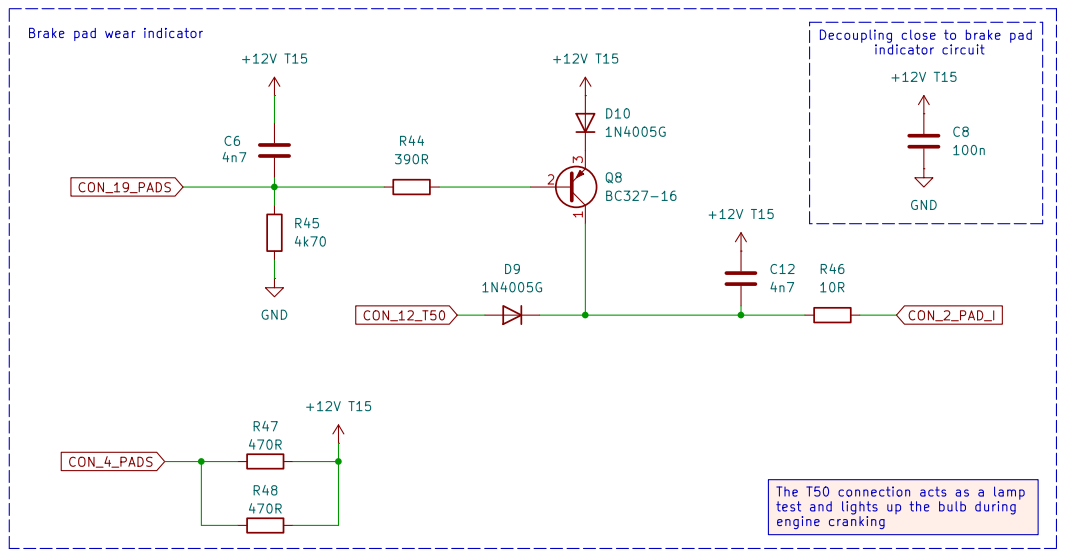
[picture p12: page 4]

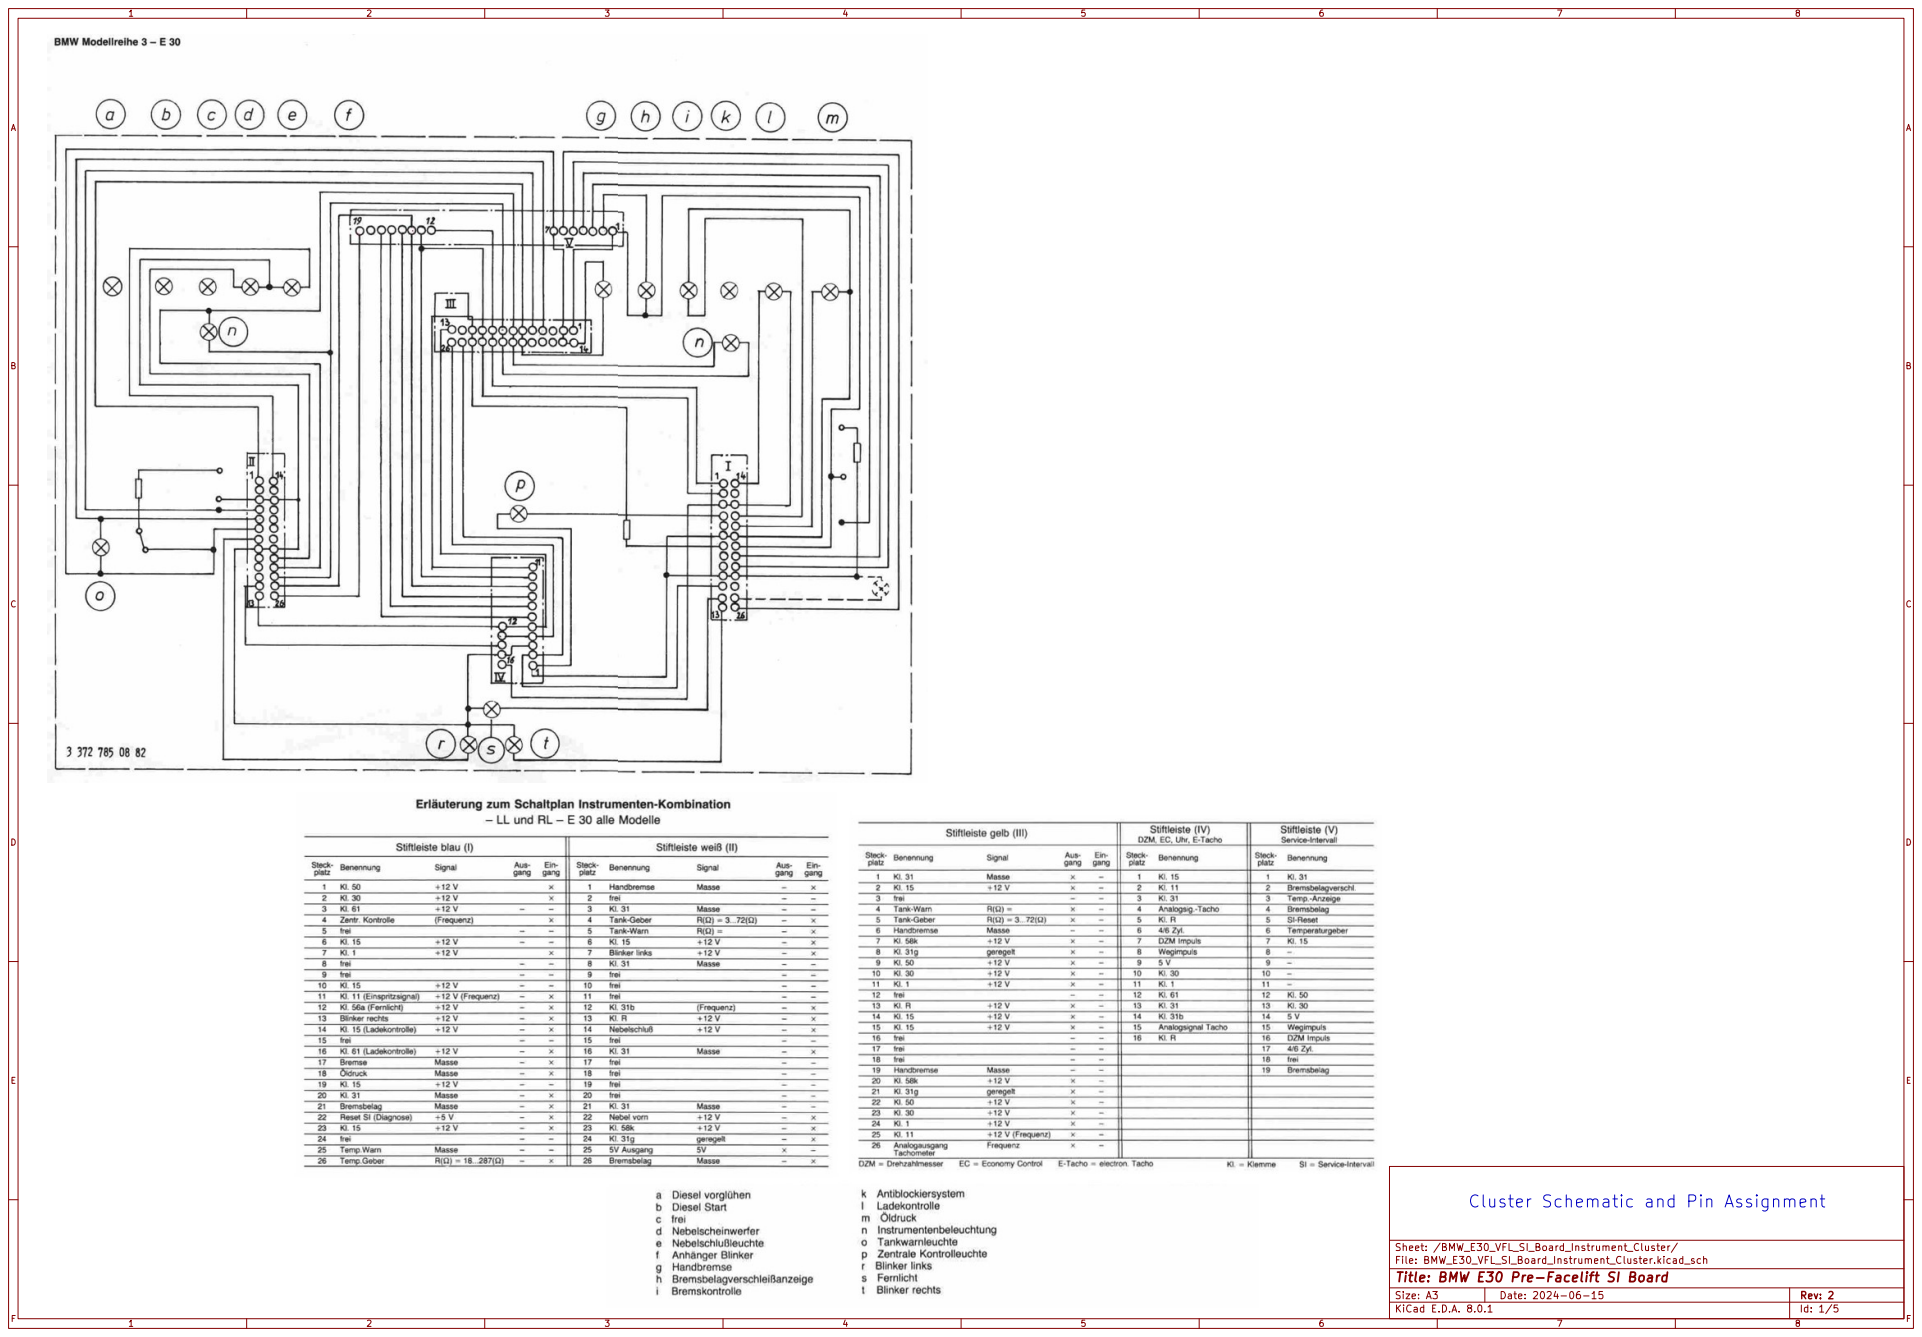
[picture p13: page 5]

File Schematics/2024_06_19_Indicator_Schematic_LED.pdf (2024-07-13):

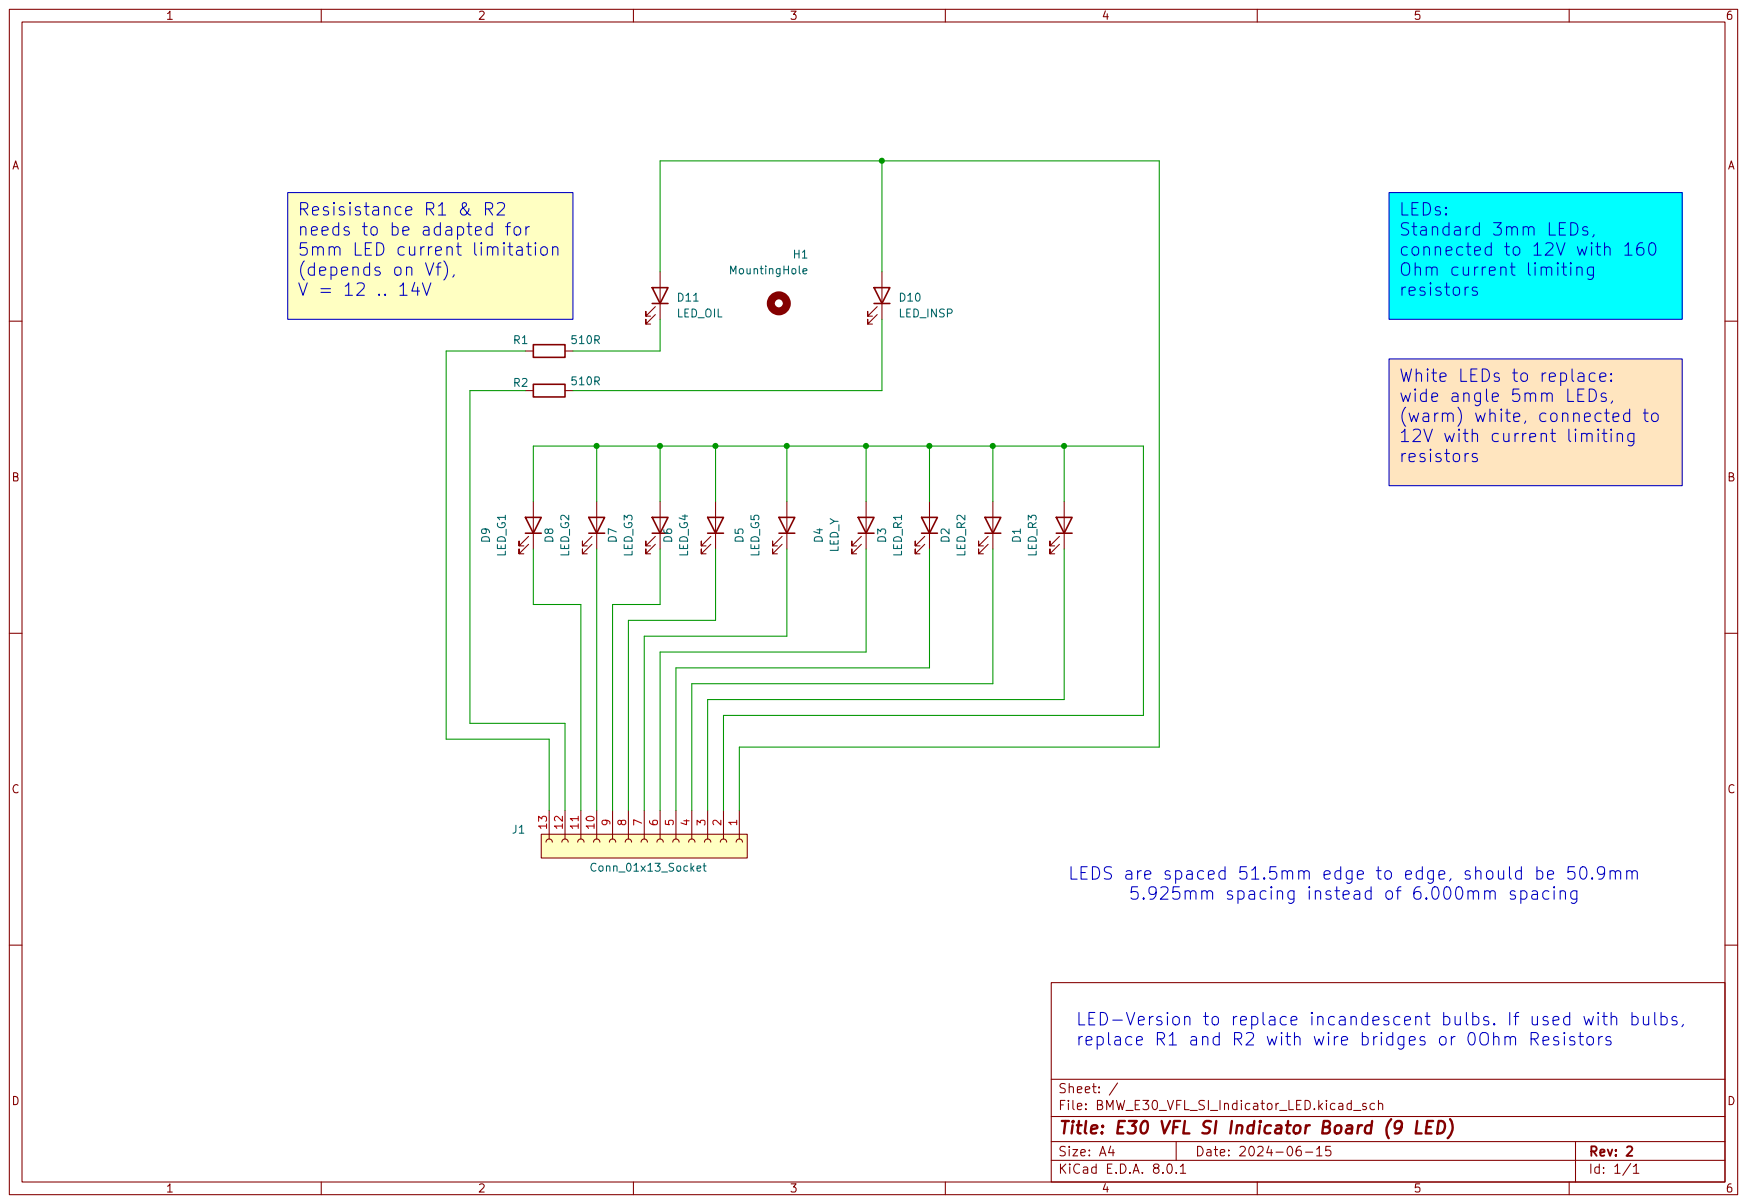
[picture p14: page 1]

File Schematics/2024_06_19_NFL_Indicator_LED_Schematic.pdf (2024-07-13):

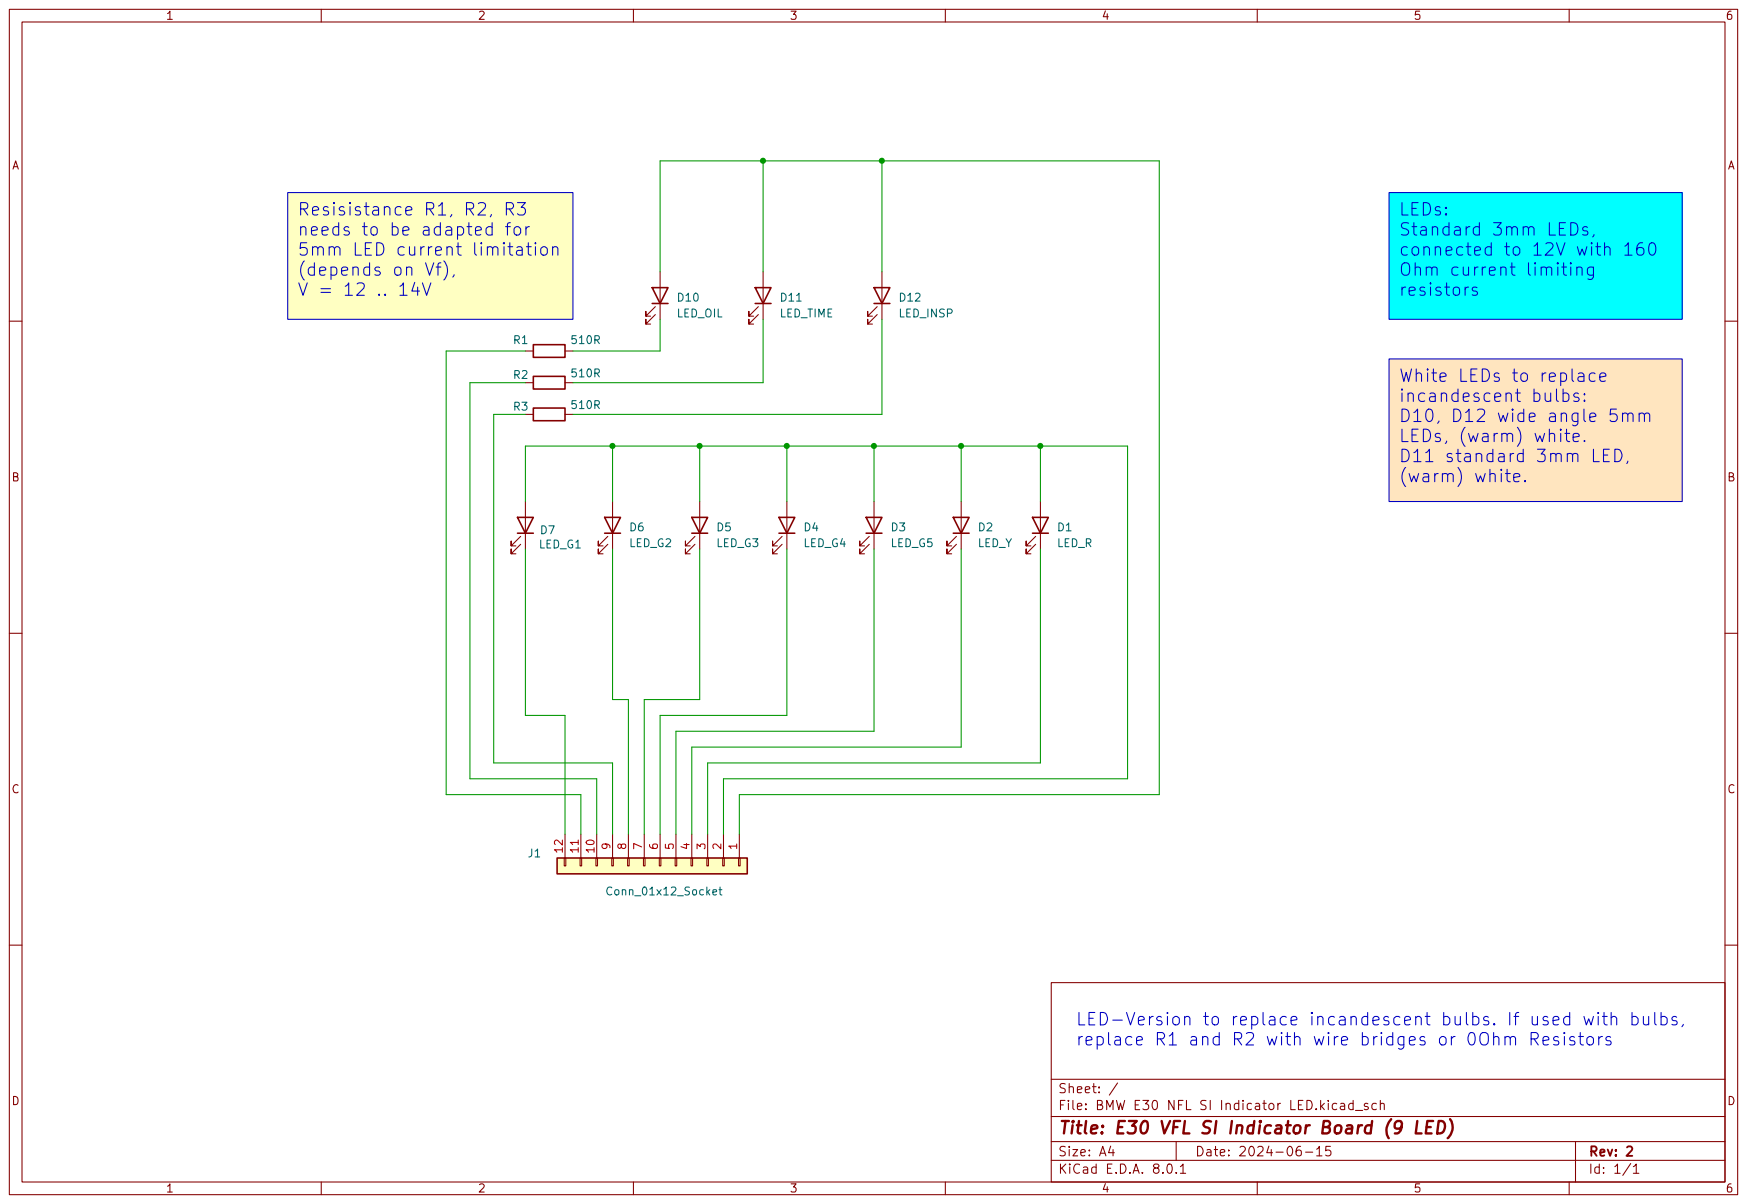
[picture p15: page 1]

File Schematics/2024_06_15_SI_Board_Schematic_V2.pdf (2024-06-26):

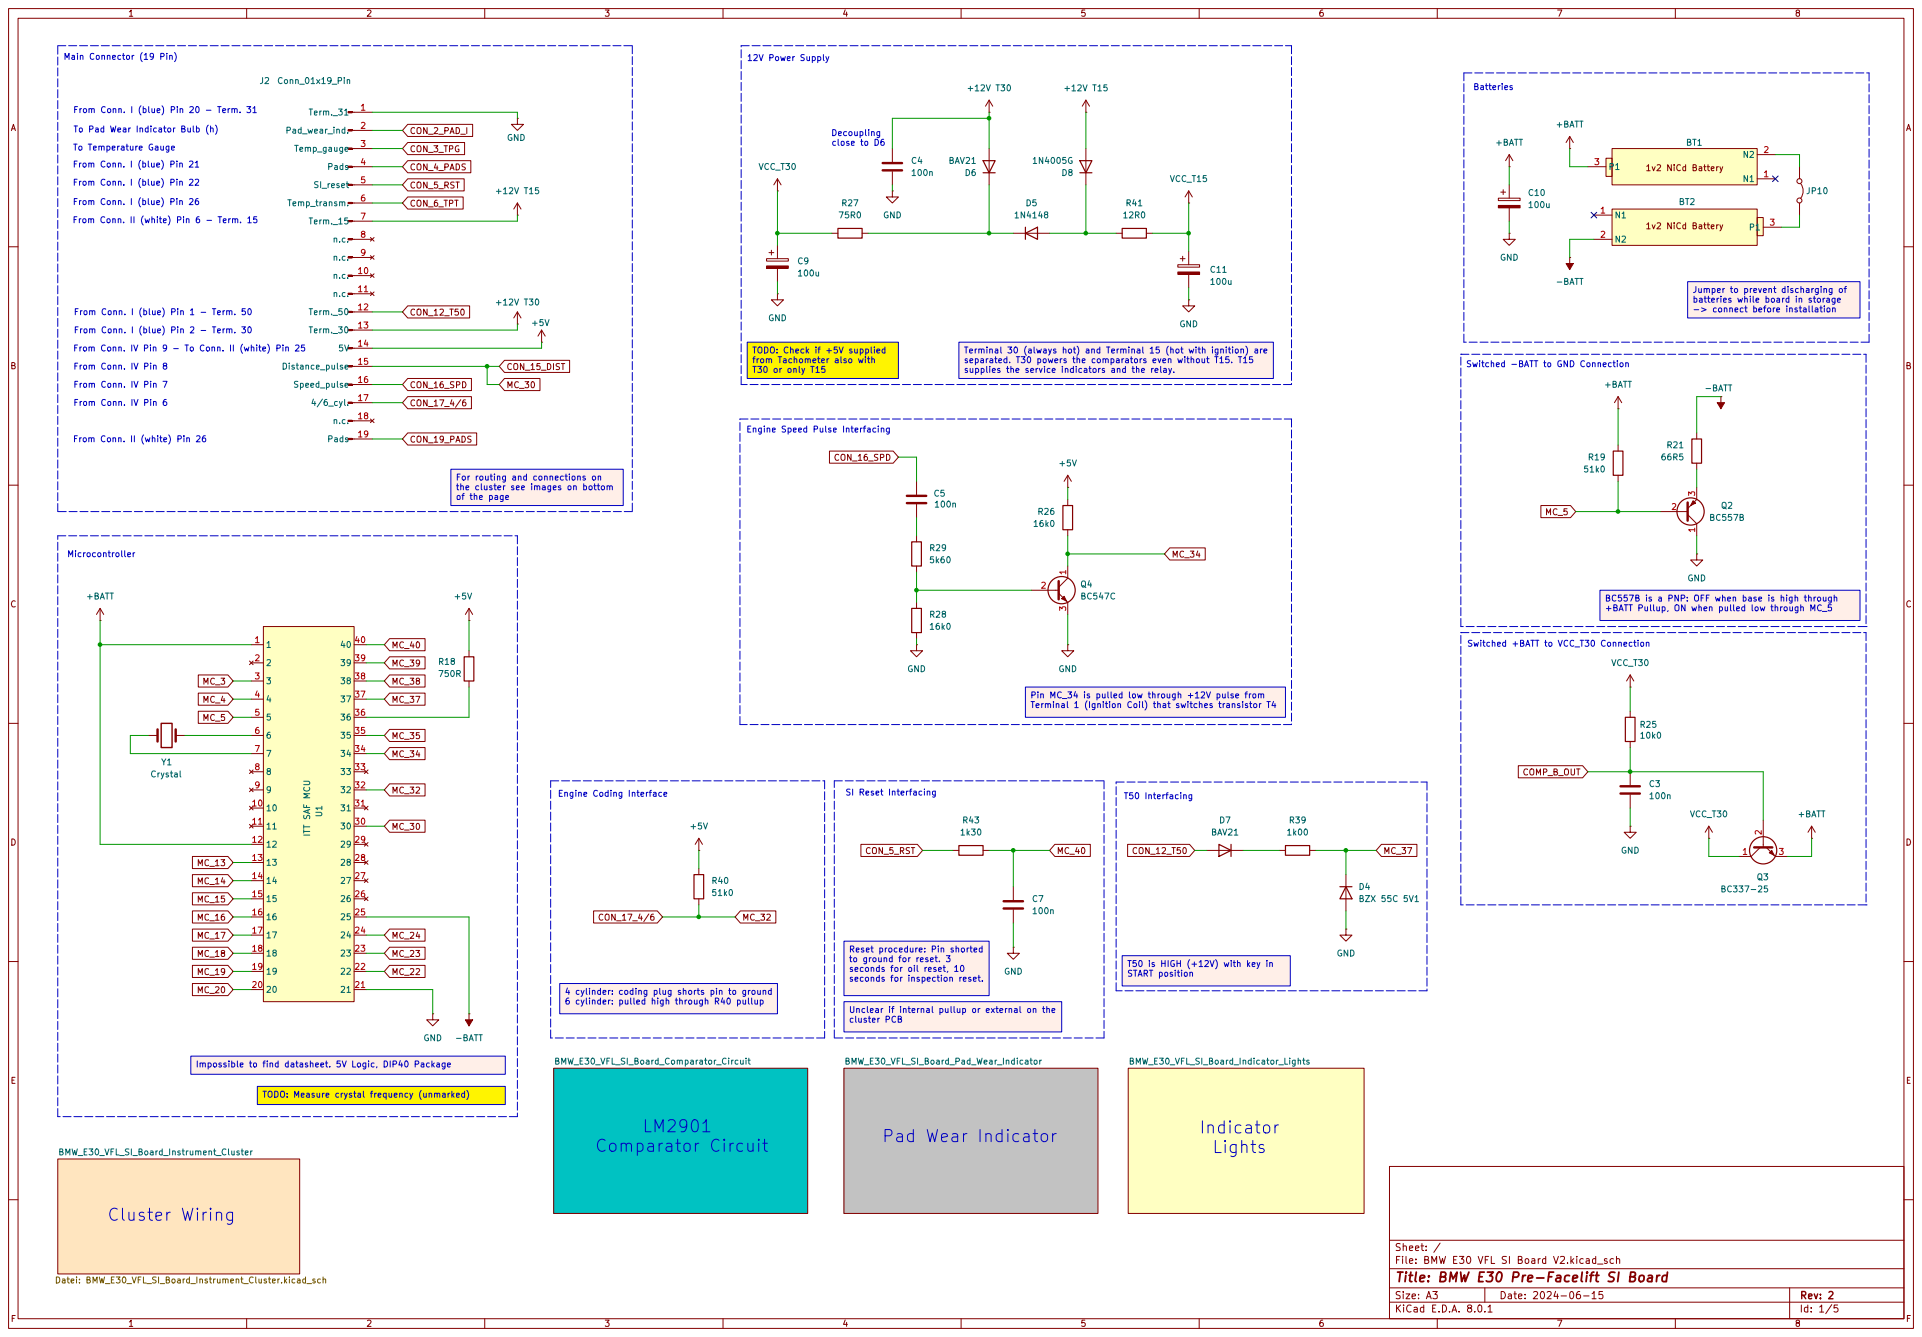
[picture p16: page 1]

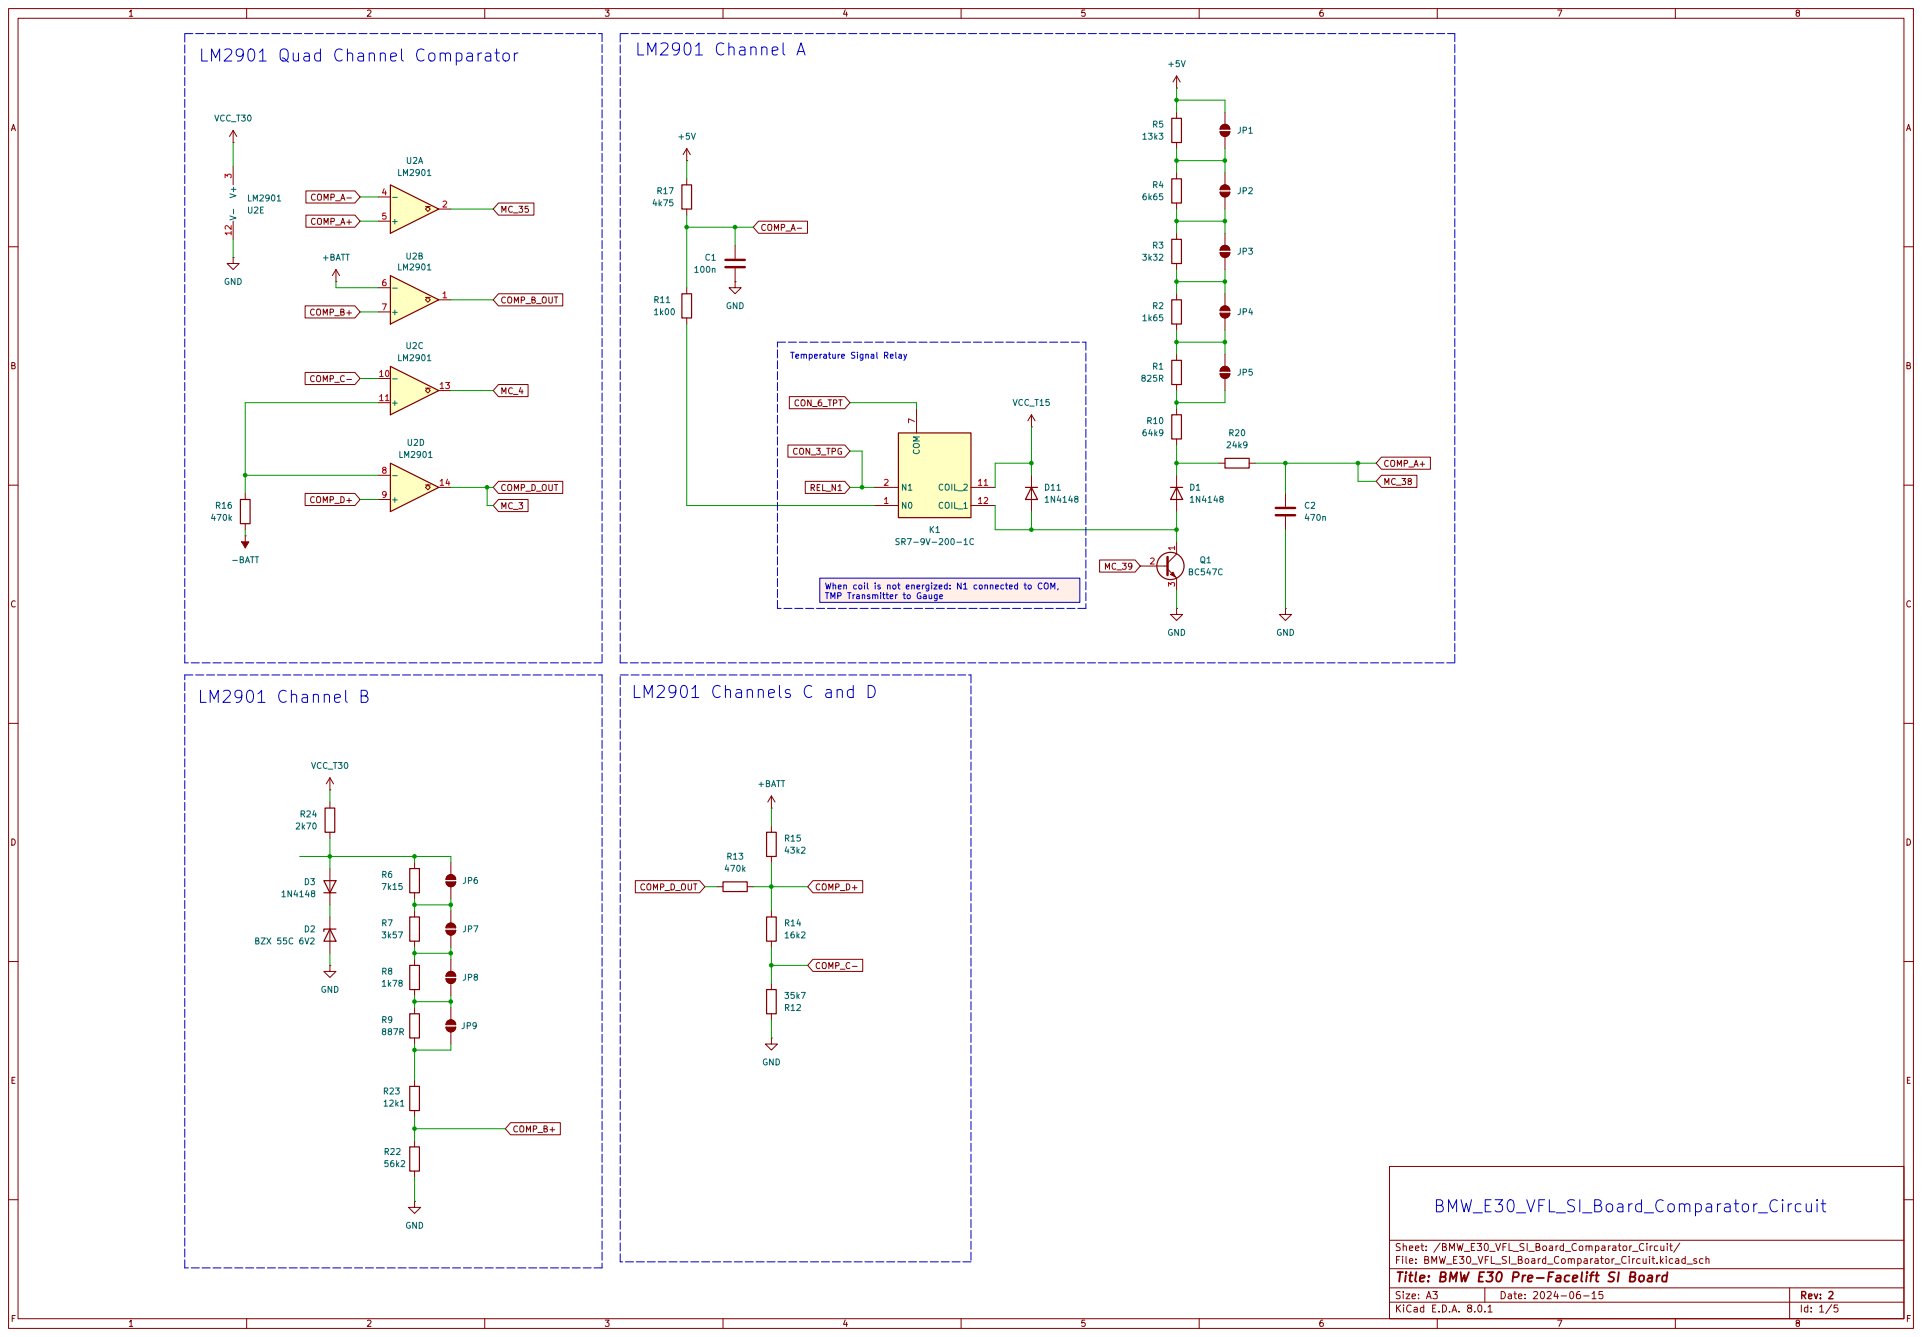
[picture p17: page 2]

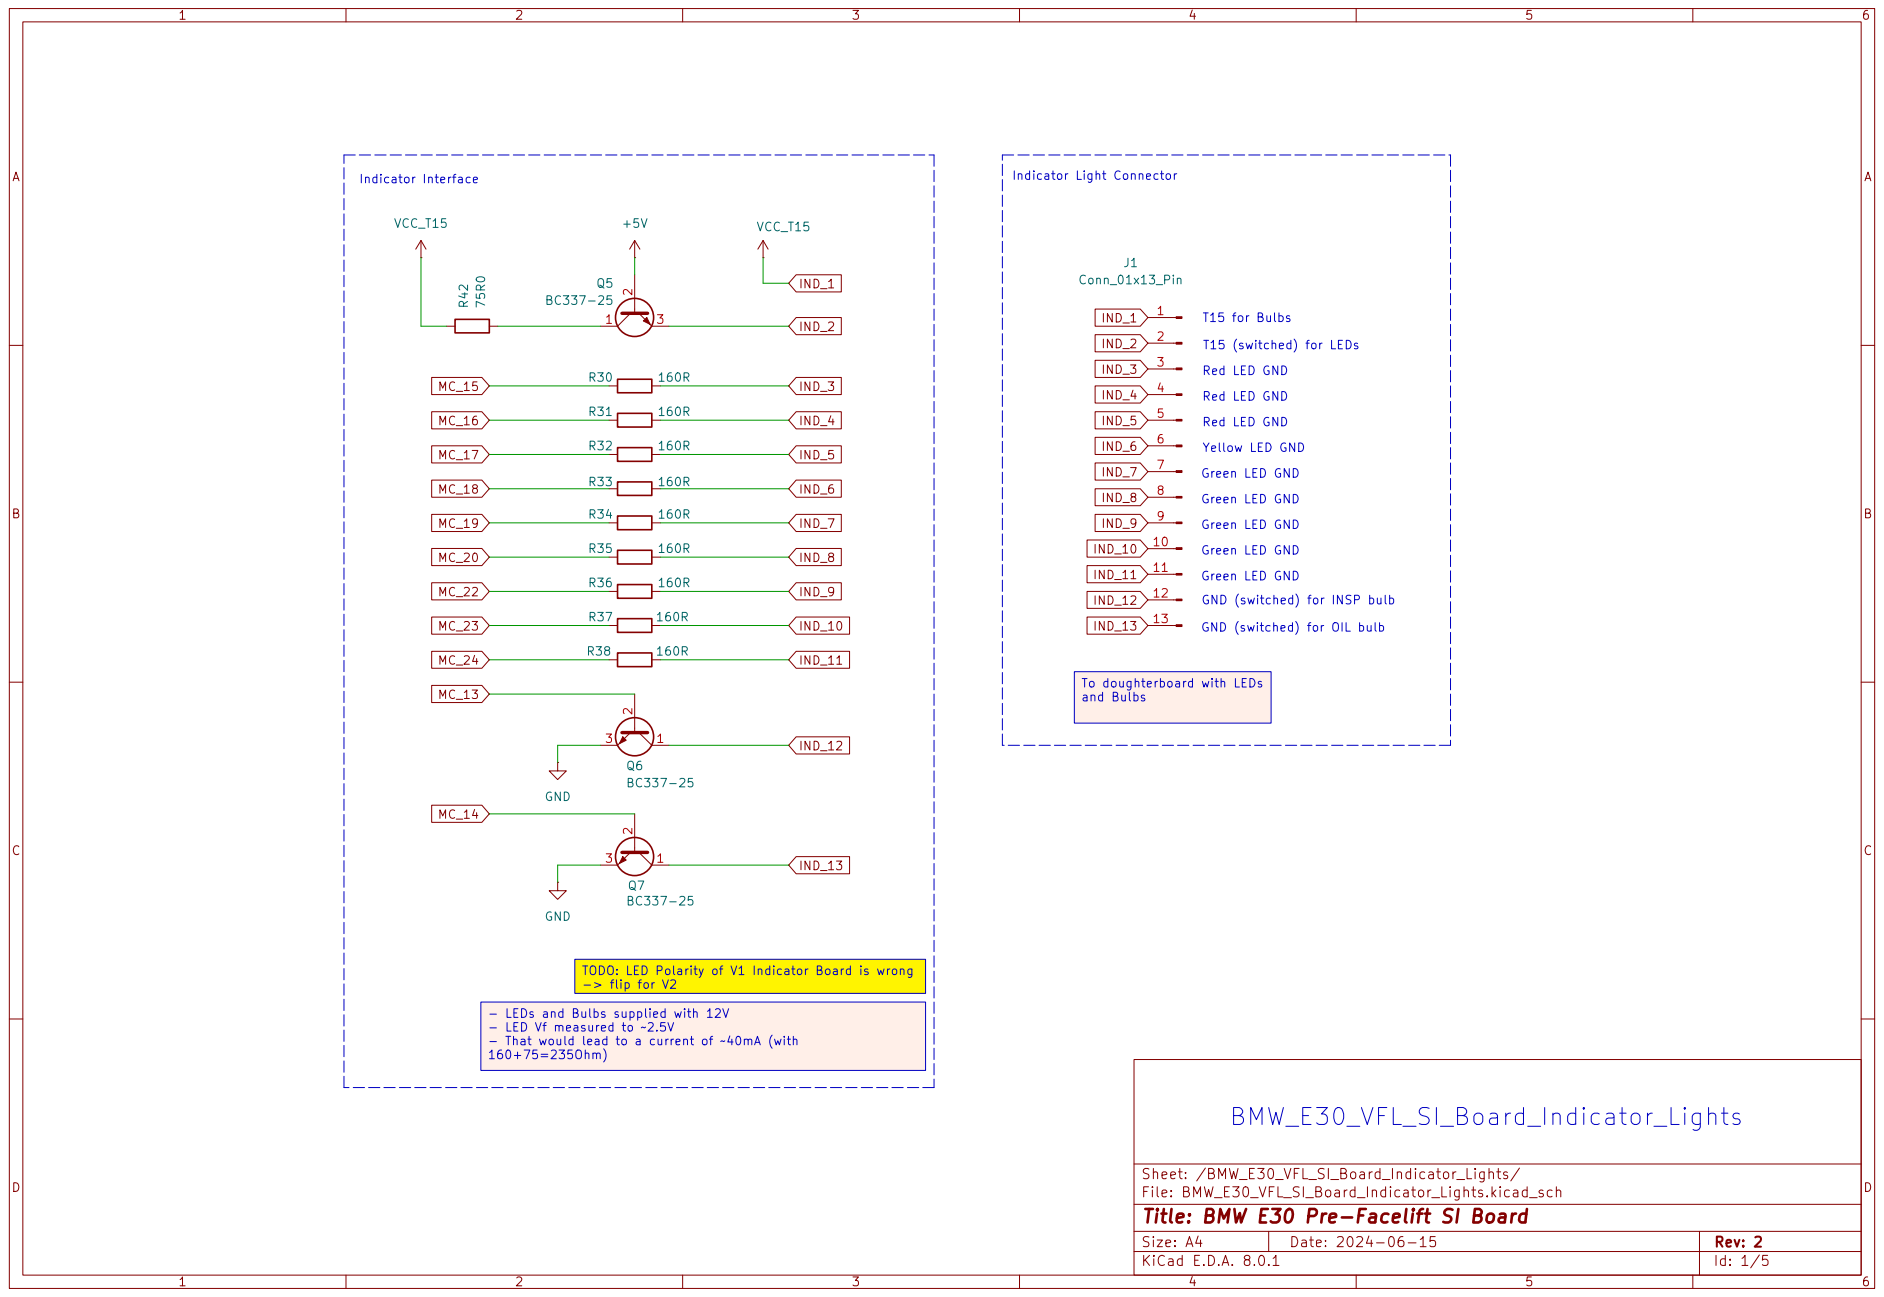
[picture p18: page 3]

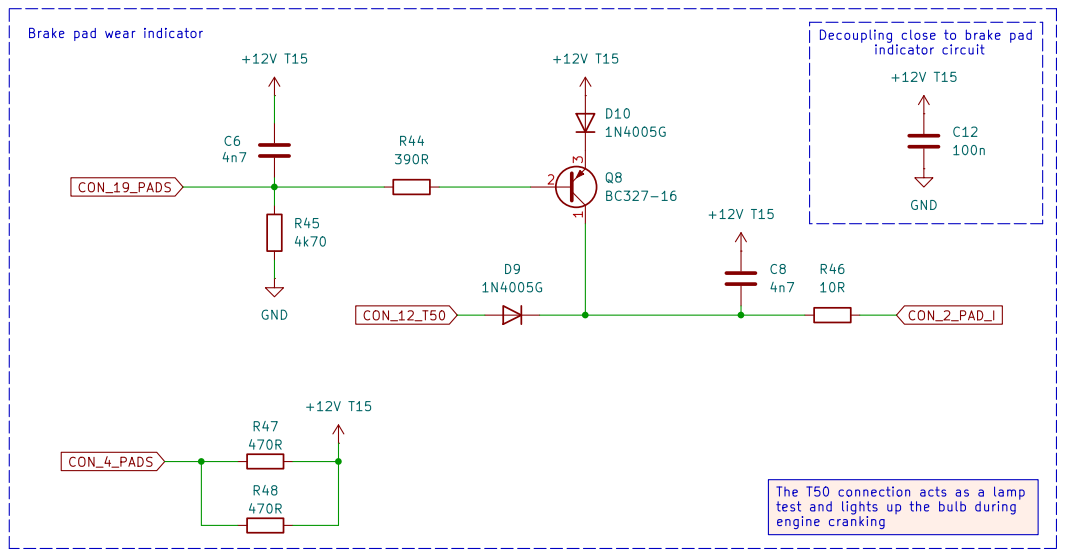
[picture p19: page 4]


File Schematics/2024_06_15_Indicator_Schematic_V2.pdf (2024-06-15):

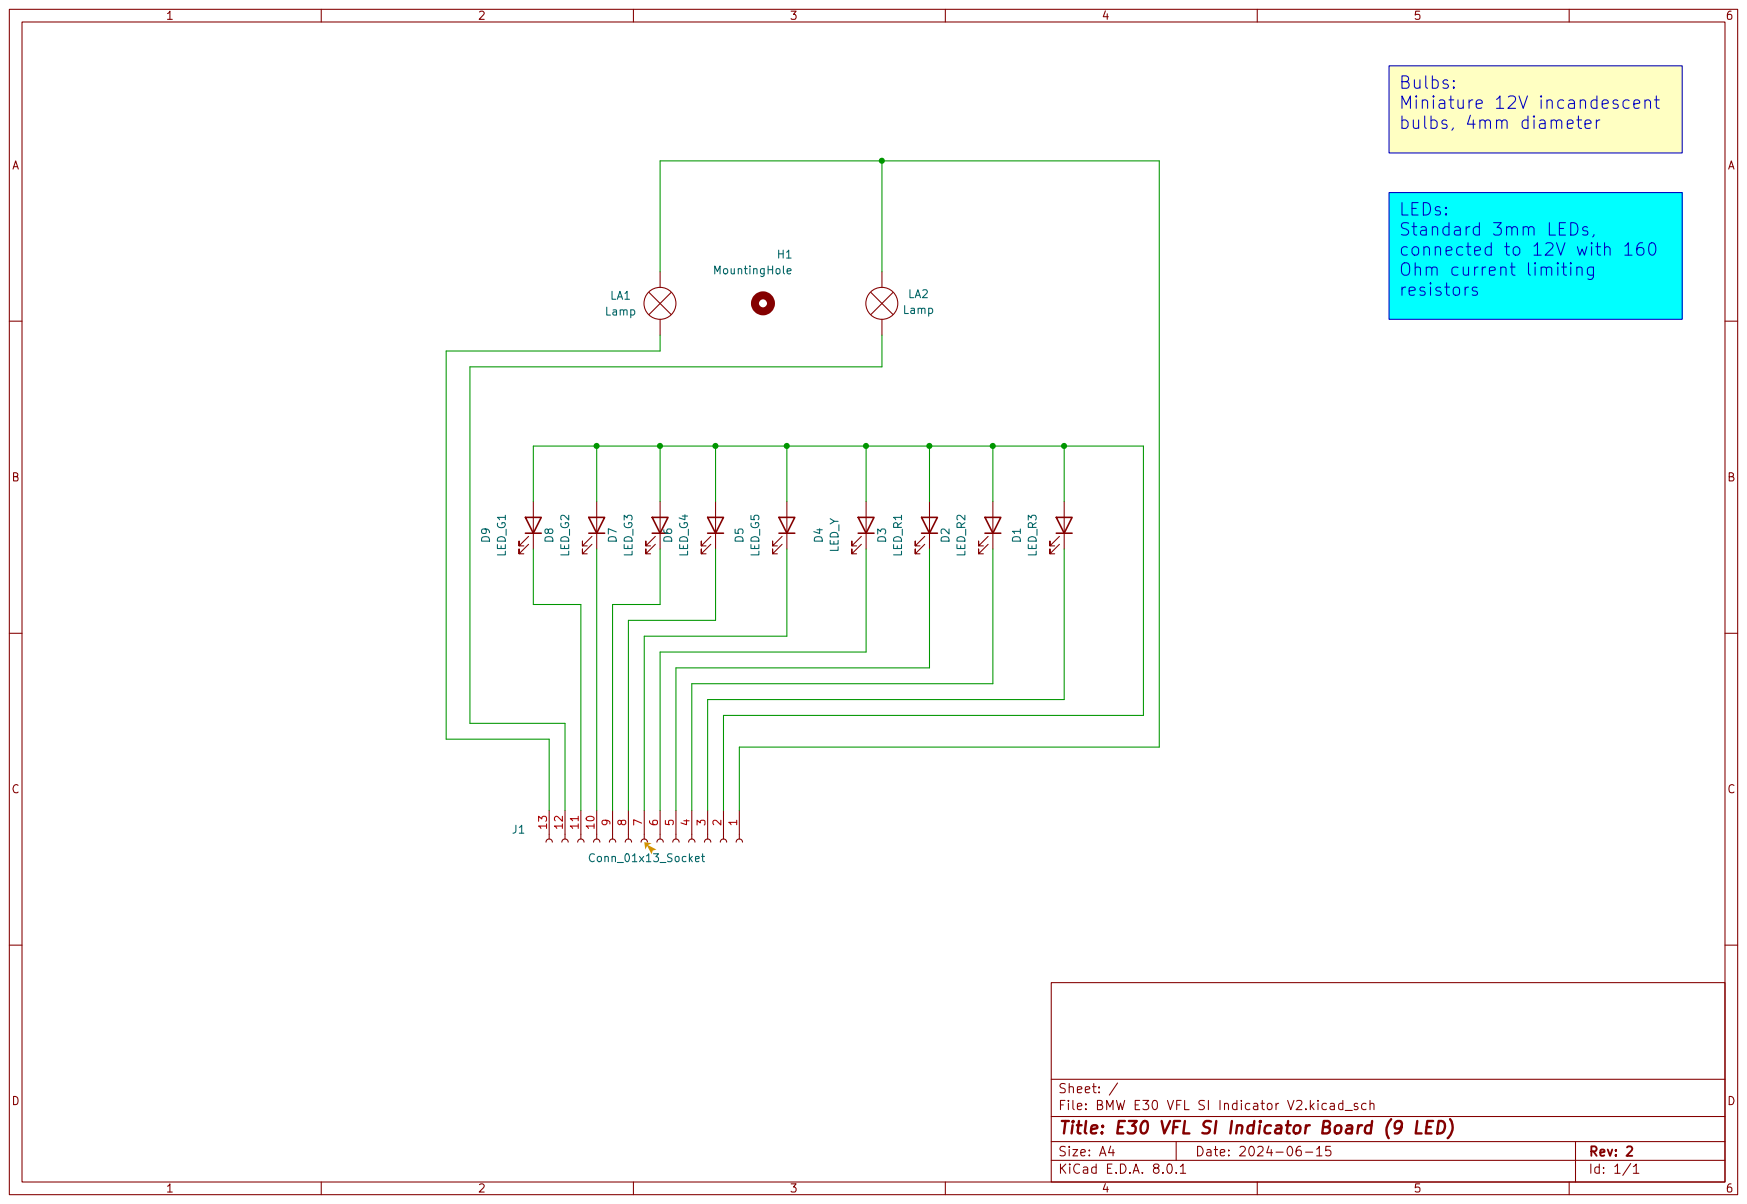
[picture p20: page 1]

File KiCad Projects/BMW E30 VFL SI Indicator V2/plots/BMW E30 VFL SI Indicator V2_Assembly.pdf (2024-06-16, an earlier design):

D Date: KiCad; E.D.A. 8.0.1 Size: A4; Rev:; Id: 1/1 Title: File: BMW; E30 VFL SI; Indicator; V2.kicad_pcb Sheet:

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

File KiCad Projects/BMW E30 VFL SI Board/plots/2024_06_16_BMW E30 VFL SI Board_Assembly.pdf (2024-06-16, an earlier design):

1 | 2 | 3 | 4 | 5 | 6 | 7 | 8

A


1 | 2 | 3 | 4 | 5 | 6 | 7 | 8 1 | 2 | 3 | 4 | 5 | 6 | 7 | 8 ABCDEF | ABCDEF Date: KiCad | E.D.A. 8.0.1 Size: A3 | Rev:

Id: 1/1 Title: File:; BMW; E30 VFL SI; Board.kicad_pcb Sheet:; SolderJumper_2_Open SolderJumper_2_Open Jumper_2_Bridged

1 | 2 | 3 | 4 | 5 | 6 | 7 | 8

A


Id: 1/1 Title: File: BMW E30 VFL SI Board.kicad_pcb Sheet:

Id: 1/1 Title: File:; BMW; E30 VFL SI; Board.kicad_pcb Sheet:

SolderJumper_2_Open SolderJumper_2_Open Jumper_2_Bridged 1 2 3 4 5 6 7 8 1 2 3 4 5 6 7 8 ABCDEF ABCDEF Date: KiCad E.D.A. 8.0.1 Size: A3 Rev:

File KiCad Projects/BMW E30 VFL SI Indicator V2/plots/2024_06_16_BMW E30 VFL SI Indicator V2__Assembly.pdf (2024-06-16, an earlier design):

D Date: KiCad; E.D.A. 8.0.1 Size: A4; Rev:; Id: 1/1 Title: File: BMW; E30 VFL SI; Indicator; V2.kicad_pcb Sheet:; LED_G1 LED_G2 LED_G3 LED_G4 LED_G5 LED_Y; LED_R3 Lamp Lamp; LED_R1 MountingHole H¹; Conn_01x13_Socket J1; LED_R2

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

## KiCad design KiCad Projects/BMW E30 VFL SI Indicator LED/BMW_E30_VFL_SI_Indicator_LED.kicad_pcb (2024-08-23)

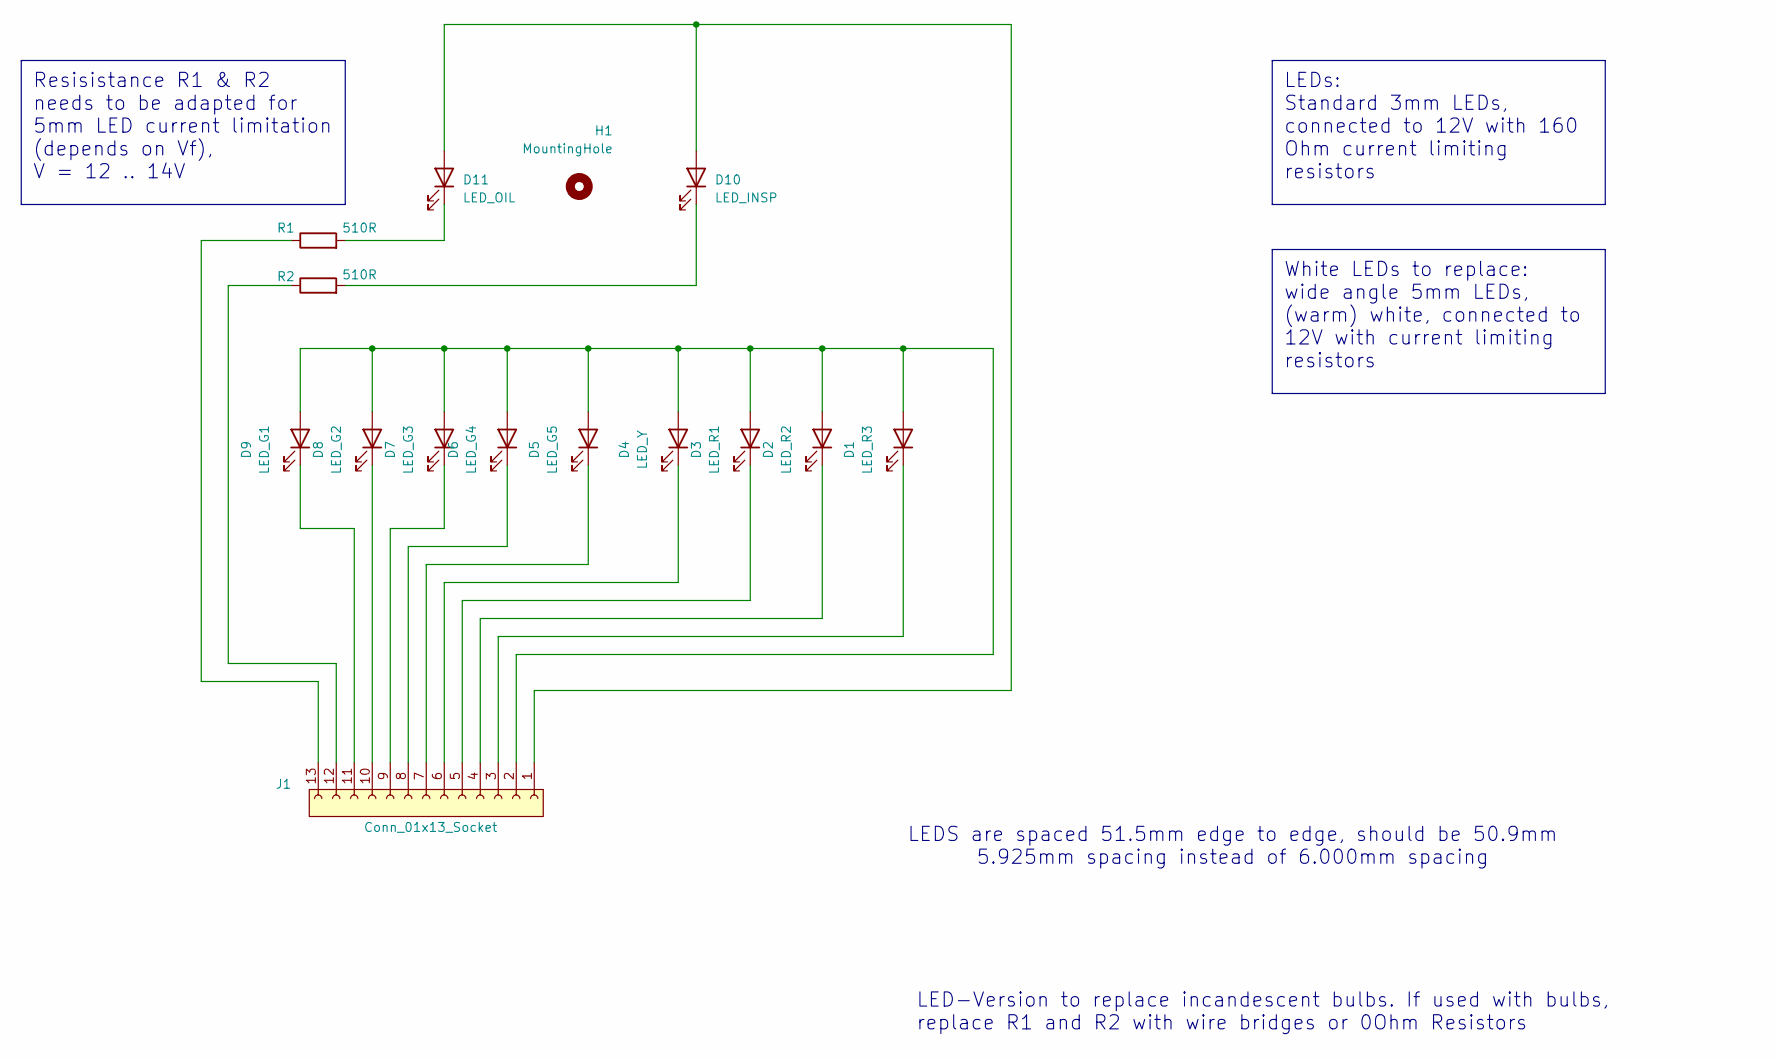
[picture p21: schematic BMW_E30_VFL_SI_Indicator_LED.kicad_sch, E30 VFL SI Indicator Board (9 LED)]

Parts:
D1: LED_R3; LED_D3.0mm
D2: LED_R2; LED_D3.0mm
D3: LED_R1; LED_D3.0mm
D4: LED_Y; LED_D3.0mm
D5: LED_G5; LED_D3.0mm
D6: LED_G4; LED_D3.0mm
D7: LED_G3; LED_D3.0mm
D8: LED_G2; LED_D3.0mm
D9: LED_G1; LED_D3.0mm
D10: LED_INSP; LED_Rectangular_W5.0mm_H2.0mm_Horizontal_O6.35mm_Z1.0mm
D11: LED_OIL; LED_Rectangular_W5.0mm_H2.0mm_Horizontal_O6.35mm_Z3.0mm
H1: MountingHole; MountingHole_6.5mm
J1: Conn_01x13_Socket; PinSocket_1x13_P2.54mm_Horizontal
R1, R2: 510R; R_Axial_DIN0207_L6.3mm_D2.5mm_P7.62mm_Horizontal

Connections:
unnamed: D1.2 (A), D2.2 (A), D3.2 (A), D4.2 (A), D5.2 (A), D6.2 (A), D7.2 (A), D8.2 (A), D9.2 (A), J1.2 (GND_LED)
unnamed: D1.1 (K), J1.3 (LED_R3)
unnamed: D2.1 (K), J1.4 (LED_R2)
unnamed: D3.1 (K), J1.5 (LED_R1)
unnamed: D4.1 (K), J1.6 (LED_Y)
unnamed: D5.1 (K), J1.7 (LED_G5)
unnamed: D6.1 (K), J1.8 (LED_G4)
unnamed: D7.1 (K), J1.9 (LED_G3)
unnamed: D8.1 (K), J1.10 (LED_G2)
unnamed: D9.1 (K), J1.11 (LED_G1)
unnamed: D10.2 (A), D11.2 (A), J1.1 (GND_BULB)
unnamed: D10.1 (K), R2.2
unnamed: D11.1 (K), R1.2
unnamed: J1.12 (BULB_INSPECTION), R2.1
unnamed: J1.13 (BULB_OILSERVICE), R1.1

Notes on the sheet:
White LEDs to replace: wide angle 5mm LEDs, (warm) white, connected to 12V with current limiting resistors
LEDs: Standard 3mm LEDs, connected to 12V with 160 Ohm current limiting resistors
Resisistance R1 & R2 needs to be adapted for 5mm LED current limitation (depends on Vf), V = 12 .. 14V
LEDS are spaced 51.5mm edge to edge, should be 50.9mm 5.925mm spacing instead of 6.000mm spacing
LED-Version to replace incandescent bulbs. If used with bulbs, replace R1 and R2 with wire bridges or 0Ohm Resistors

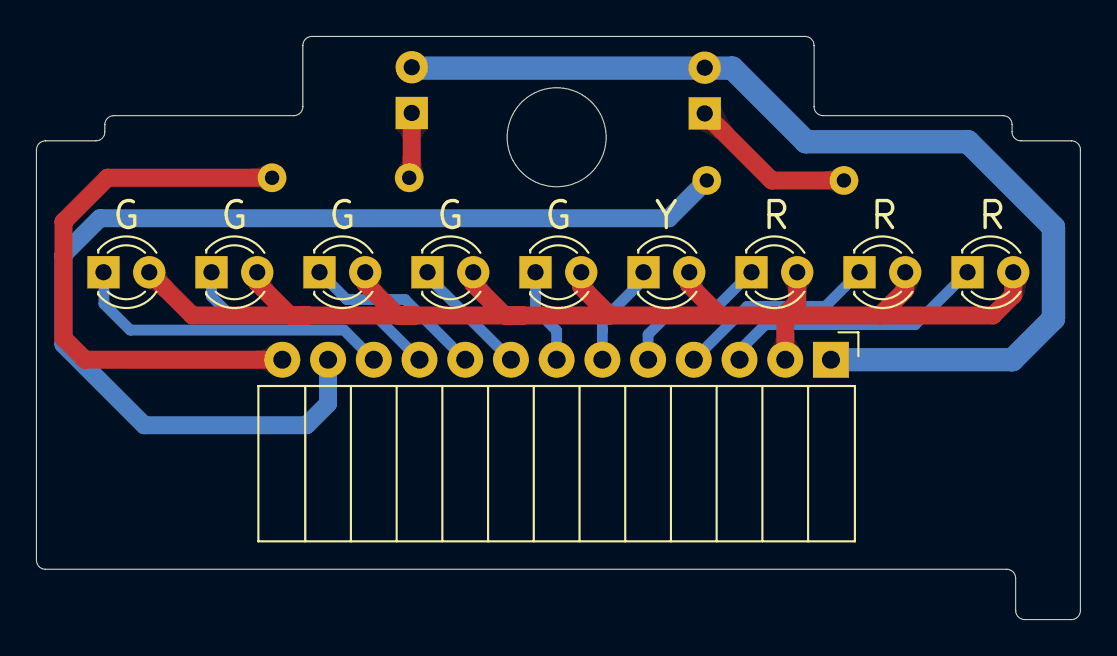
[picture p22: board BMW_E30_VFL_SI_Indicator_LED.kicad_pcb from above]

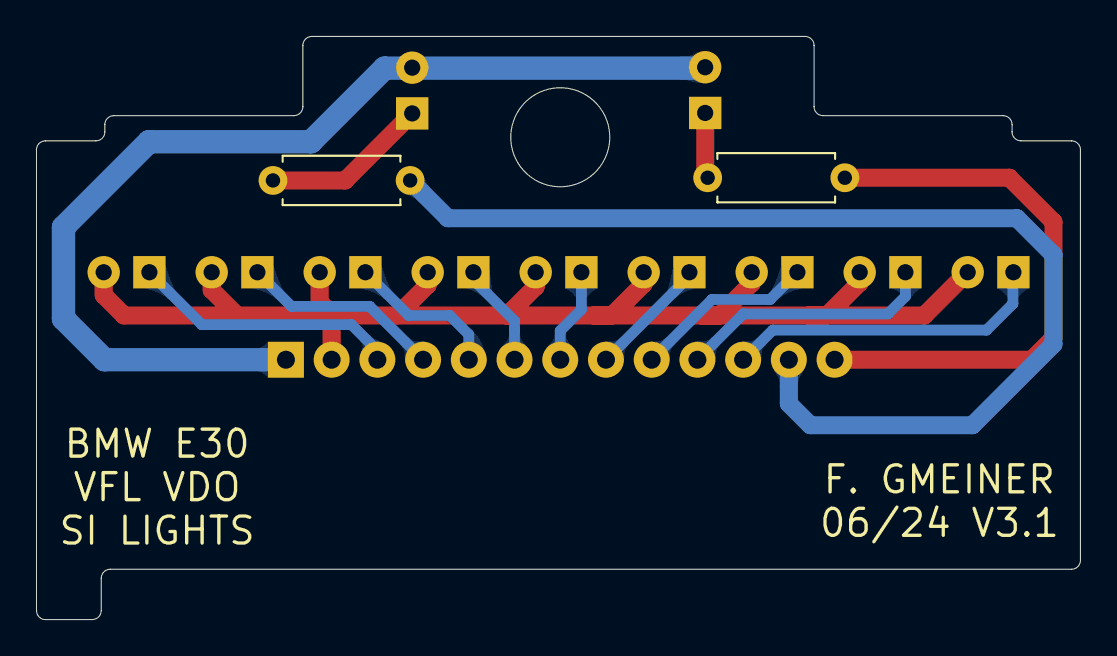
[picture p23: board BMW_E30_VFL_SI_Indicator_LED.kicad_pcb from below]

Board: 2 copper layers, 58.0 x 32.4 mm, 15 parts (2 on the bottom side), 15 nets.

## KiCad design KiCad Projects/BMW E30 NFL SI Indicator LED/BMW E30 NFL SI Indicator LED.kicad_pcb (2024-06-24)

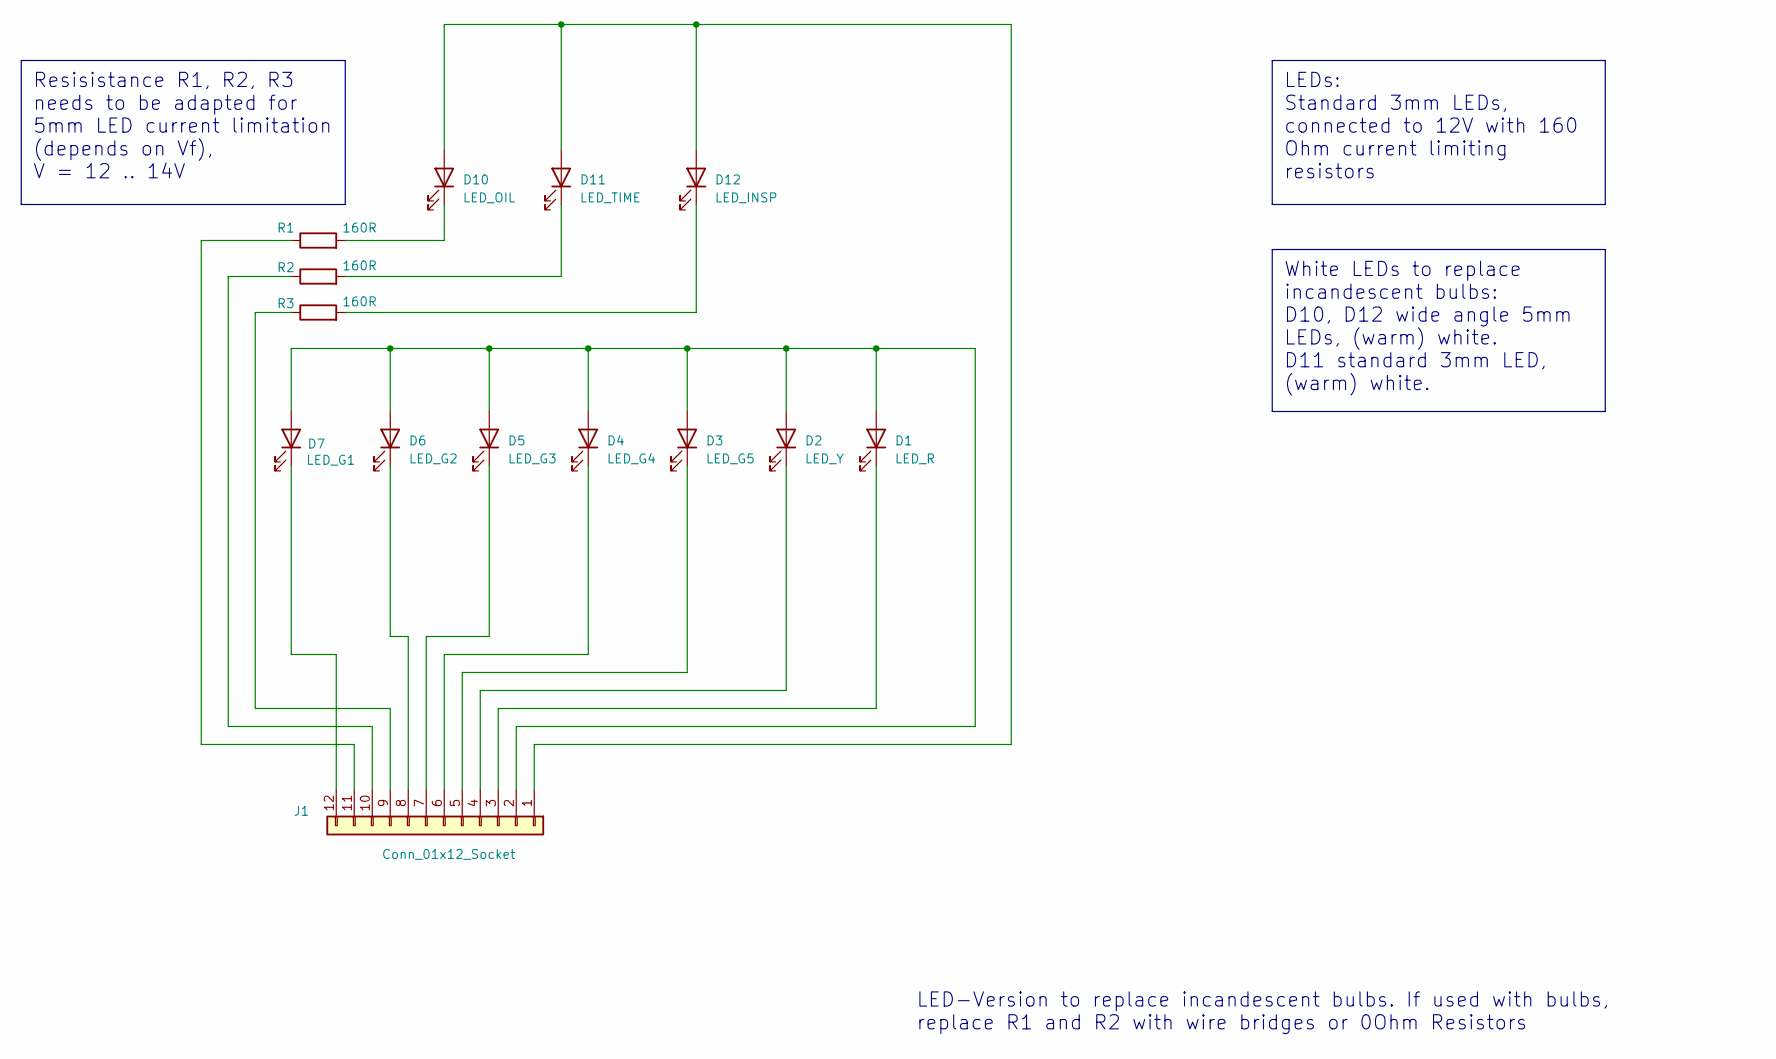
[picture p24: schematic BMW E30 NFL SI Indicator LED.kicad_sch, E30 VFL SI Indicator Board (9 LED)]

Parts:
D1: LED_R; LED_D3.0mm
D2: LED_Y; LED_D3.0mm
D3: LED_G5; LED_D3.0mm
D4: LED_G4; LED_D3.0mm
D5: LED_G3; LED_D3.0mm
D6: LED_G2; LED_D3.0mm
D7: LED_G1; LED_D3.0mm
D10: LED_OIL; LED_Rectangular_W5.0mm_H2.0mm_Horizontal_O3.81mm_Z1.0mm
D11: LED_TIME; LED_D3.0mm_Clear
D12: LED_INSP; LED_Rectangular_W5.0mm_H2.0mm_Horizontal_O3.81mm_Z1.0mm
J1: Conn_01x12_Socket; PinSocket_1x12_P2.54mm_Horizontal
R1, R2, R3: 160R; R_Axial_DIN0207_L6.3mm_D2.5mm_P7.62mm_Horizontal

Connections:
unnamed: D1.2 (A), D2.2 (A), D3.2 (A), D4.2 (A), D5.2 (A), D6.2 (A), D7.2 (A), J1.2 (T15_LEDS)
unnamed: D1.1 (K), J1.3 (LED_R)
unnamed: D2.1 (K), J1.4 (LED_Y)
unnamed: D3.1 (K), J1.5 (LED_G5)
unnamed: D4.1 (K), J1.6 (LED_G4)
unnamed: D5.1 (K), J1.7 (LED_G3)
unnamed: D6.1 (K), J1.8 (LED_G2)
unnamed: D7.1 (K), J1.12 (LED_G1)
unnamed: D10.2 (A), D11.2 (A), D12.2 (A), J1.1 (T15_BULBS)
unnamed: D10.1 (K), R1.2
unnamed: D11.1 (K), R2.2
unnamed: D12.1 (K), R3.2
unnamed: J1.9 (BULB_INSP), R3.1
unnamed: J1.11 (BULB_OIL), R1.1
unnamed: J1.10 (BULB_TIME), R2.1

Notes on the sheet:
White LEDs to replace incandescent bulbs: D10, D12 wide angle 5mm LEDs, (warm) white. D11 standard 3mm LED, (warm) white.
LEDs: Standard 3mm LEDs, connected to 12V with 160 Ohm current limiting resistors
Resisistance R1, R2, R3 needs to be adapted for 5mm LED current limitation (depends on Vf), V = 12 .. 14V
LED-Version to replace incandescent bulbs. If used with bulbs, replace R1 and R2 with wire bridges or 0Ohm Resistors

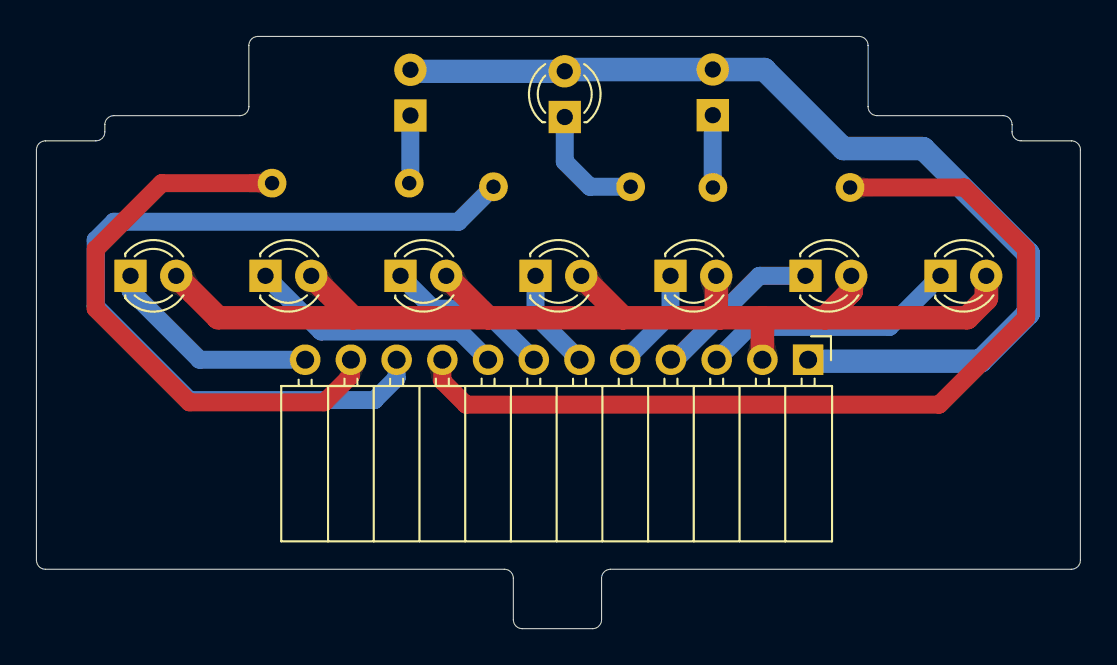
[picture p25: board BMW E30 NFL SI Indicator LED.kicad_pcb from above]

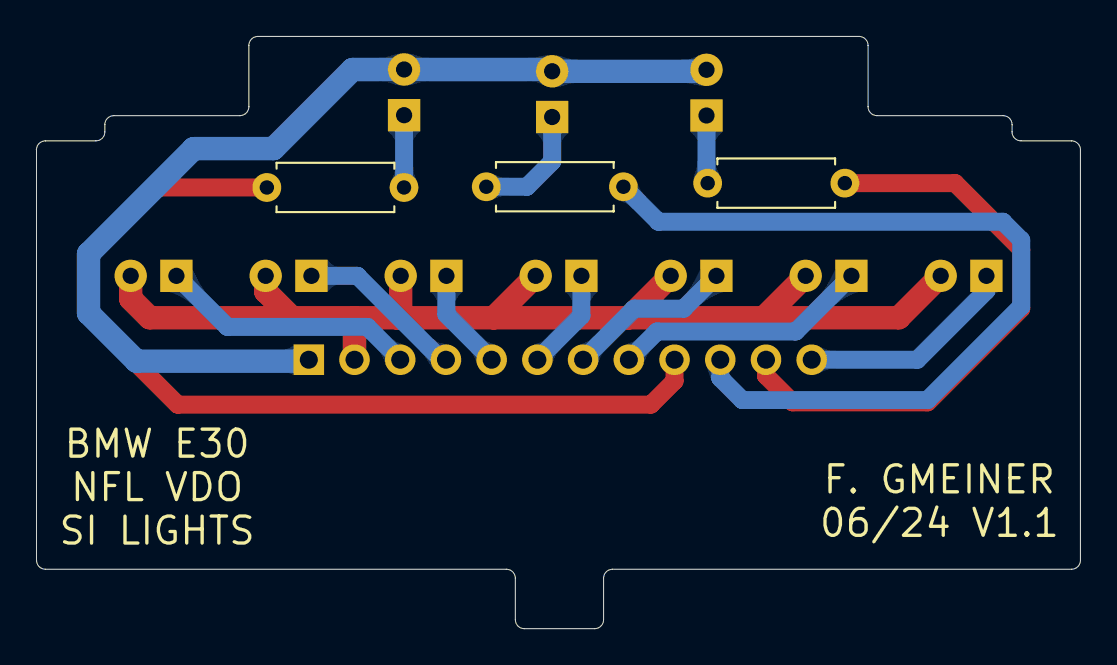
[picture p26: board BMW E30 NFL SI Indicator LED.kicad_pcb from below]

Board: 2 copper layers, 58.0 x 32.9 mm, 14 parts (3 on the bottom side), 15 nets.

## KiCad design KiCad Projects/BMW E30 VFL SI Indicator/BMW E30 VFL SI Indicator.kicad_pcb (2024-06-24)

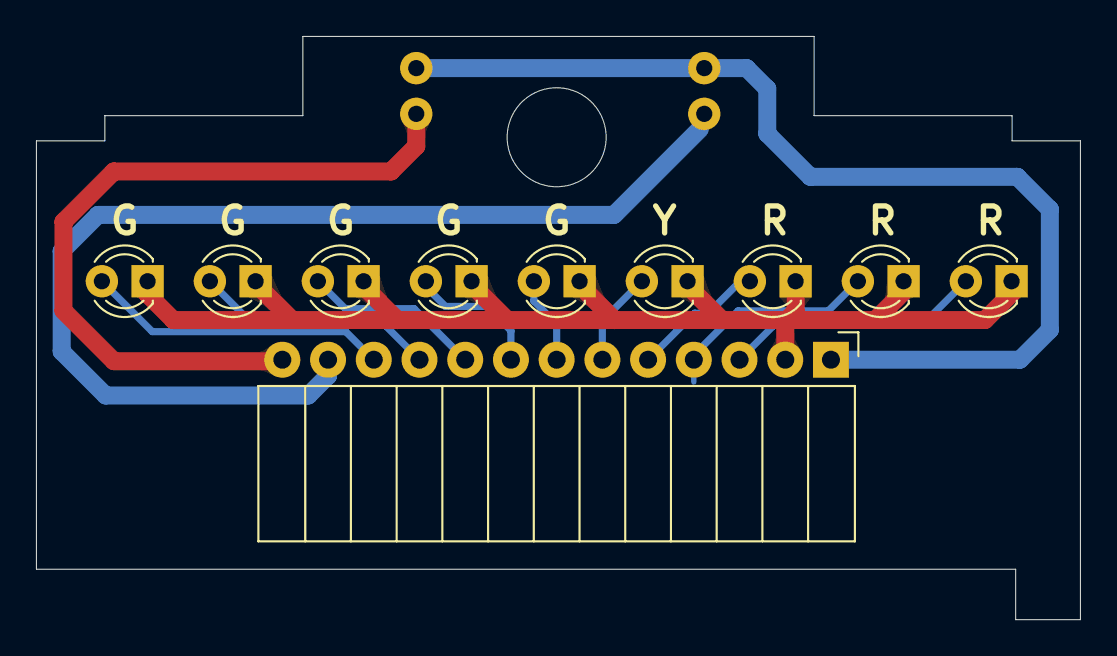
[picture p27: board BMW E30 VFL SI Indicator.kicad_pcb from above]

Board: 2 copper layers, 58.0 x 32.4 mm, 13 parts (0 on the bottom side), 13 nets.

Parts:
D1: LED_R3; LED_D3.0mm
D2: LED_R2; LED_D3.0mm
D3: LED_R1; LED_D3.0mm
D4: LED_Y; LED_D3.0mm
D5: LED_G5; LED_D3.0mm
D6: LED_G4; LED_D3.0mm
D7: LED_G3; LED_D3.0mm
D8: LED_G2; LED_D3.0mm
D9: LED_G1; LED_D3.0mm
H1: MountingHole; MountingHole_5.5mm
J1: Conn_01x13_Socket; PinSocket_1x13_P2.54mm_Horizontal
LA1, LA2: Lamp; Lamp_D4.0mm_Horizontal_O3.81mm_Z2.0mm

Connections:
unnamed: D1.2 (A), J1.3 (LED_R3)
unnamed: D1.1 (K), D2.1 (K), D3.1 (K), D4.1 (K), D5.1 (K), D6.1 (K), D7.1 (K), D8.1 (K), D9.1 (K), J1.2 (GND_LED)
unnamed: D2.2 (A), J1.4 (LED_R2)
unnamed: D3.2 (A), J1.5 (LED_R1)
unnamed: D4.2 (A), J1.6 (LED_Y)
unnamed: D5.2 (A), J1.7 (LED_G5)
unnamed: D6.2 (A), J1.8 (LED_G4)
unnamed: D7.2 (A), J1.9 (LED_G3)
unnamed: D8.2 (A), J1.10 (LED_G2)
unnamed: D9.2 (A), J1.11 (LED_G1)
unnamed: J1.12 (BULB_INSPECTION), LA2.1 (-)
unnamed: J1.13 (BULB_OILSERVICE), LA1.2 (+)
unnamed: J1.1 (GND_BULB), LA1.1 (-), LA2.2 (+)

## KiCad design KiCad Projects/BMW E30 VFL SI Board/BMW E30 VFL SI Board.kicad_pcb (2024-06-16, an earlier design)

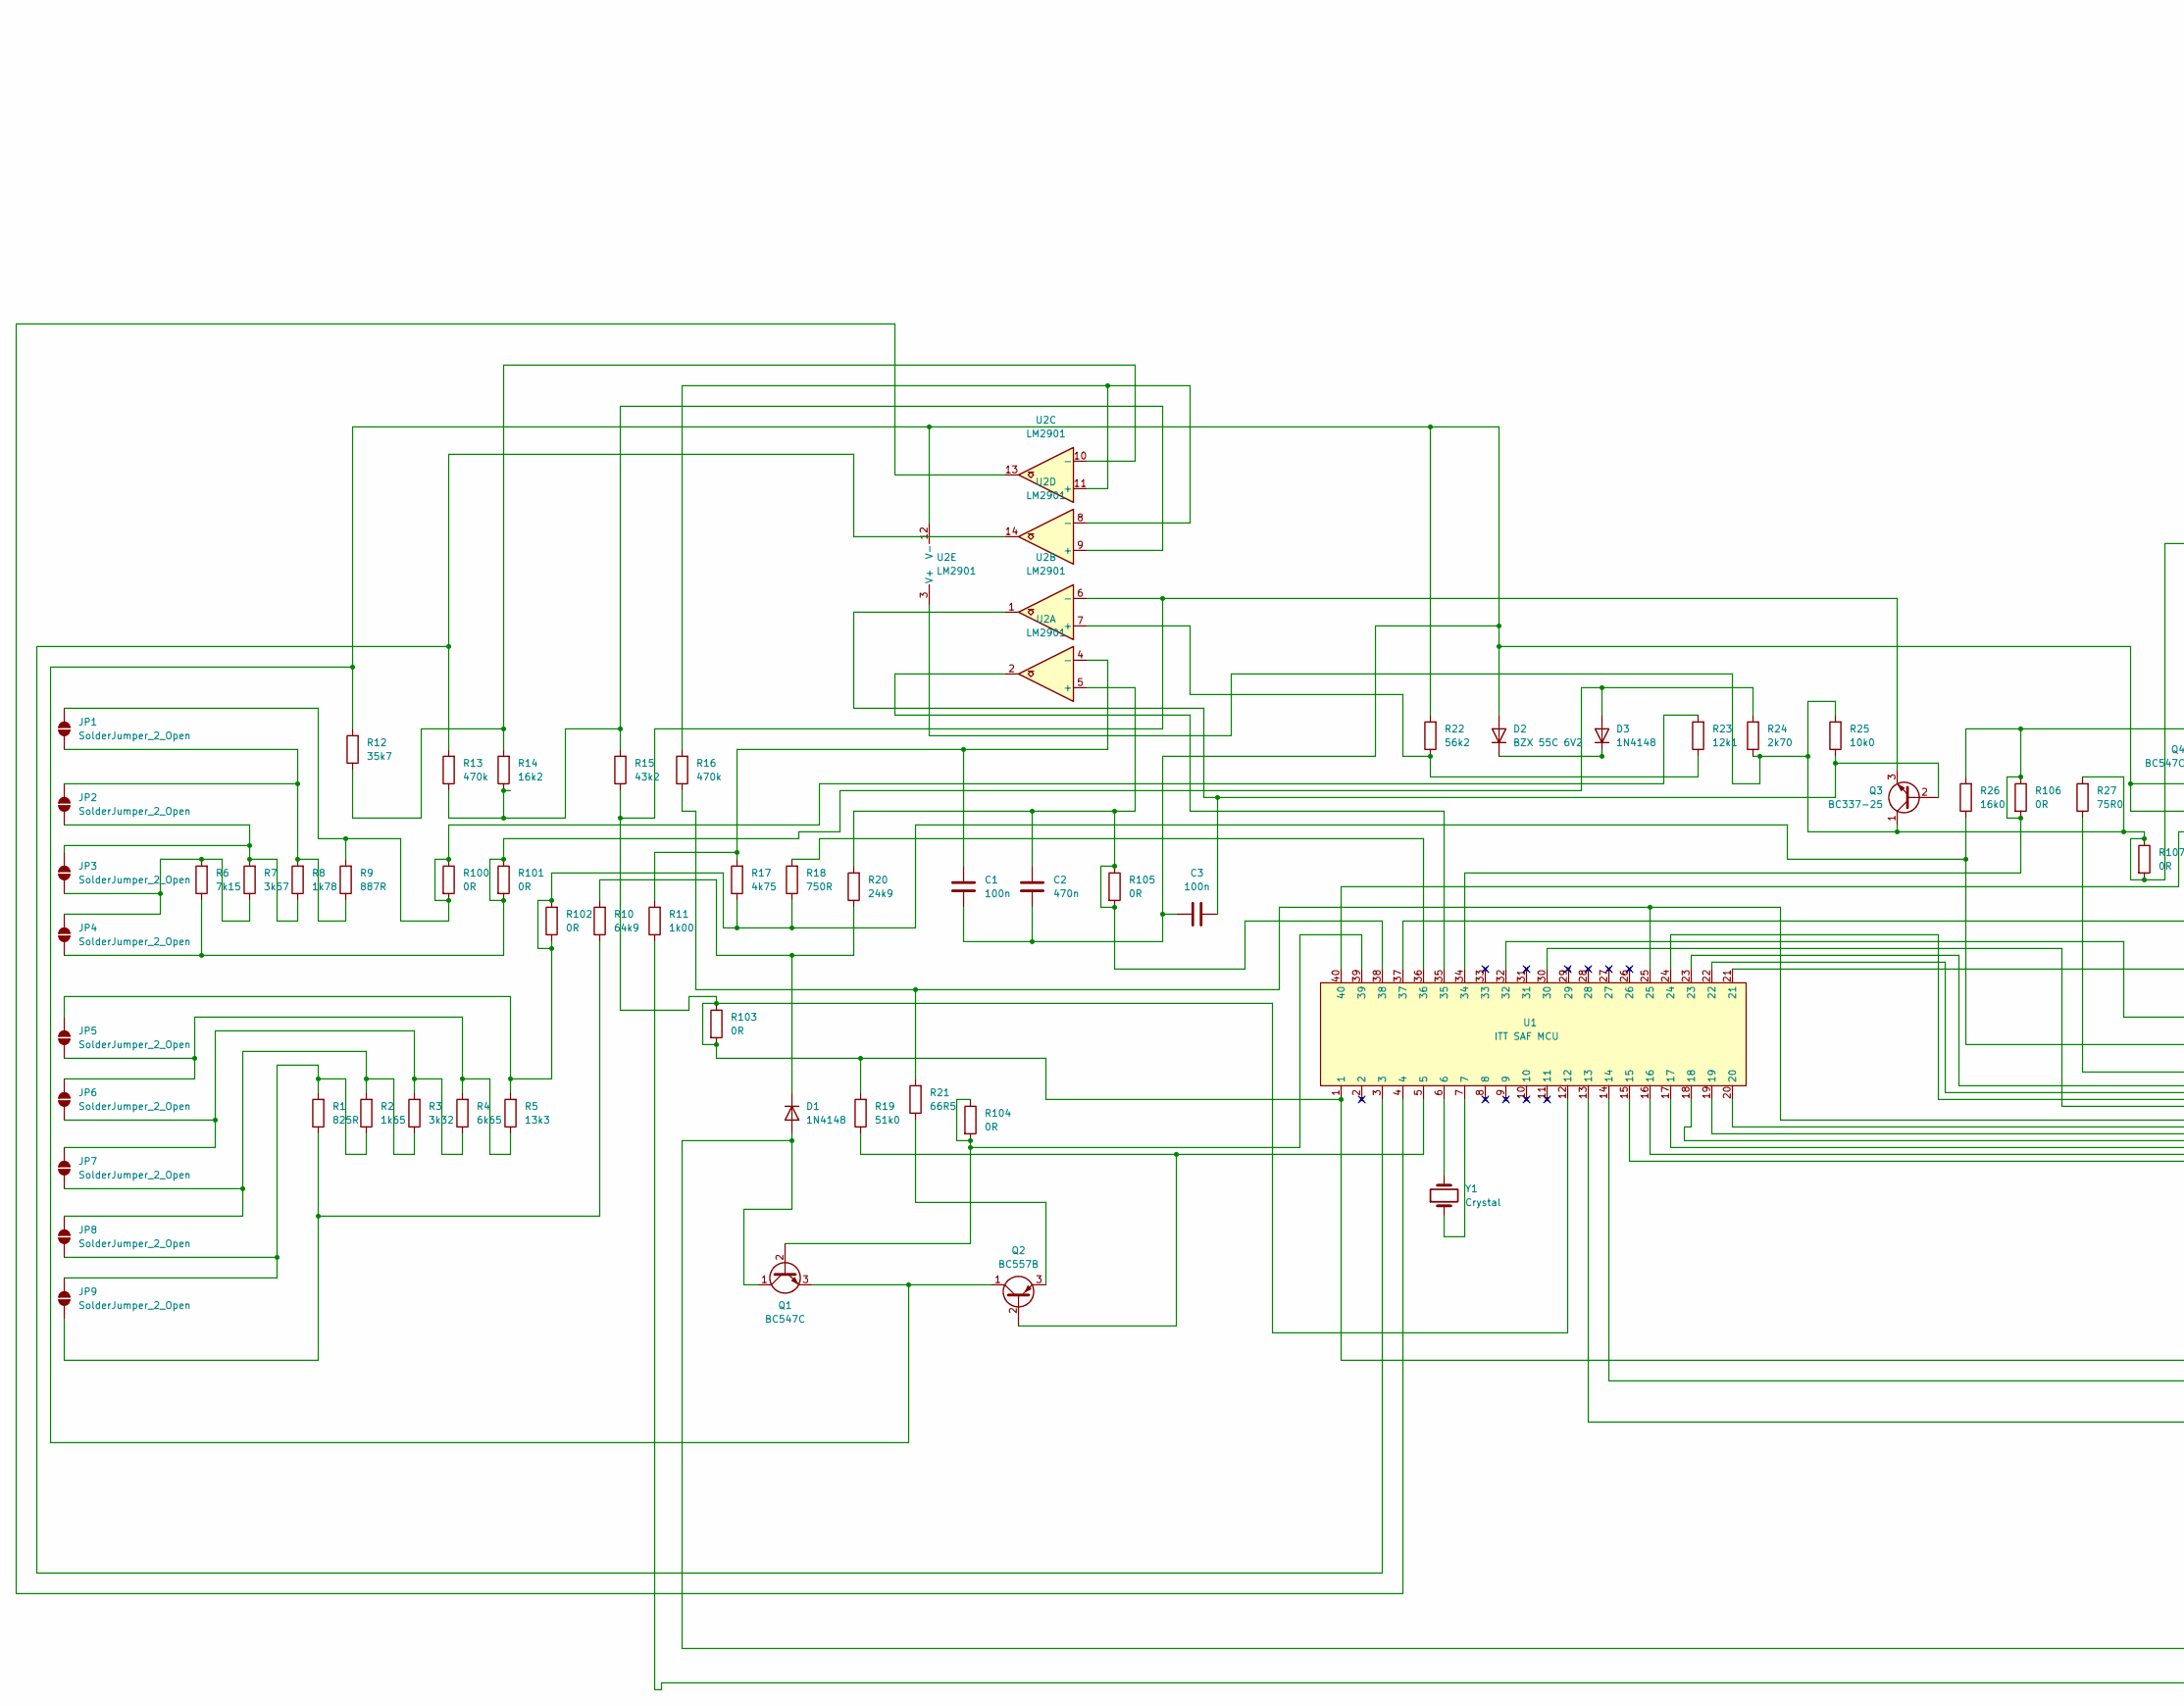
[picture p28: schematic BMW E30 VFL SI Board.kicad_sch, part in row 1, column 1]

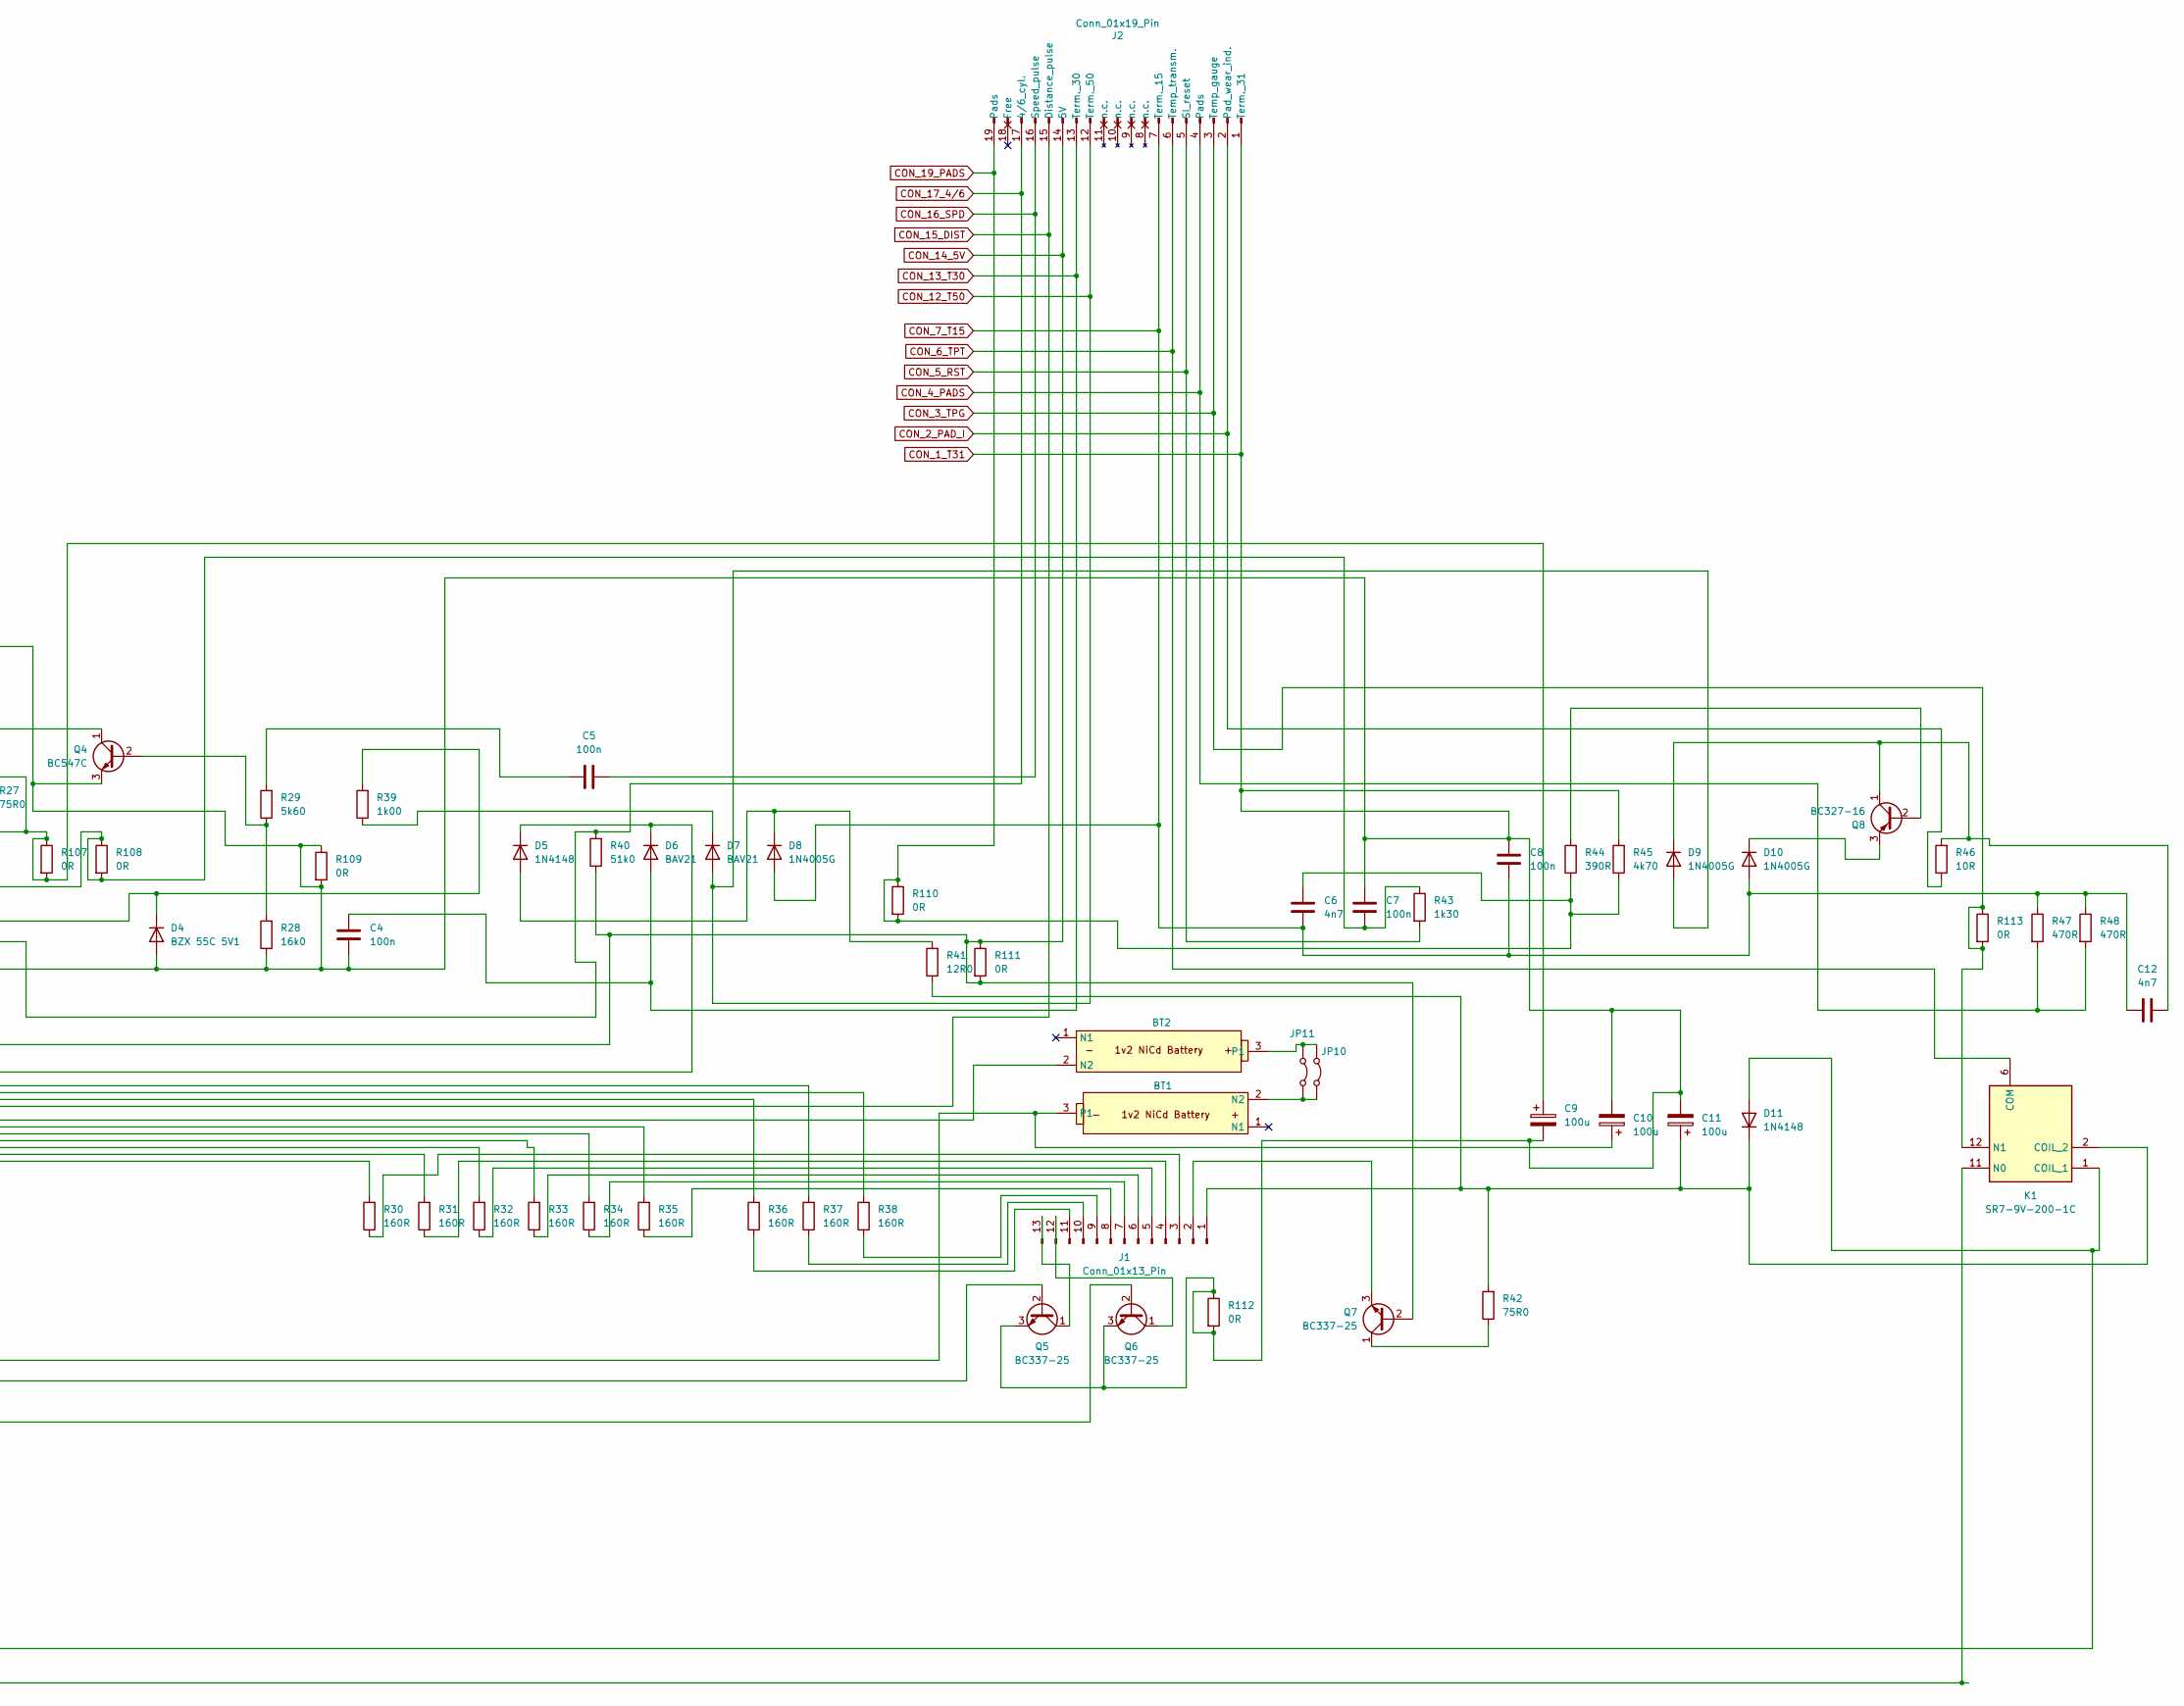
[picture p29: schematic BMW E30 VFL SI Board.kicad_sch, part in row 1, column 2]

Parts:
BT1, BT2: E30 SI Battery NiCd AA
C1, C3, C4, C7, C8: 100n; C_Rect_L7.0mm_W2.5mm_P5.00mm
C2: 470n; C_Rect_L7.2mm_W5.5mm_P5.00mm_FKS2_FKP2_MKS2_MKP2
C5: 100n; C_Rect_L7.2mm_W2.5mm_P5.00mm_FKS2_FKP2_MKS2_MKP2
C6, C12: 4n7; C_Disc_D8.0mm_W2.5mm_P5.00mm
C9, C10: 100u; CP_Axial_L16.0mm_D8.5mm_P22.5mm_Horizontal
C11: 100u; CP_Axial_L18.0mm_D8.5mm_P22.5mm_Horizontal
D1, D3, D11: 1N4148; D_DO-35_SOD27_P10.16mm_Horizontal
D2: BZX 55C 6V2; D_DO-35_SOD27_P10.16mm_Horizontal
D4: BZX 55C 5V1; D_DO-35_SOD27_P10.16mm_Horizontal
D5: 1N4148; D_DO-35_SOD27_P7.62mm_Horizontal
D6: BAV21; D_DO-35_SOD27_P10.16mm_Horizontal
D7: BAV21; D_DO-35_SOD27_P12.70mm_Horizontal
D8, D9, D10: 1N4005G; D_DO-41_SOD81_P12.70mm_Horizontal
J1: Conn_01x13_Pin; PinHeader_1x13_P2.54mm_Vertical
J2: Conn_01x19_Pin; E30_SI_Connector_19Pin_P3.5
JP1, JP2, JP3, JP4, JP5, JP6, JP7, JP8, JP9: SolderJumper_2_Open; SolderJumper-2_P1.3mm_Open_Pad1.0x1.5mm
JP10: Jumper_2_Bridged; PinHeader_1x02_P2.54mm_Vertical
JP11: Jumper_2_Bridged; SolderJumper-2_P1.3mm_Open_RoundedPad1.0x1.5mm
K1: SR7-9V-200-1C; SR79V2001C; Mouser Part Number 179-SR7-9V-200-1C
Q1, Q4: BC547C; TO-92_Inline_Wide
Q2: BC557B; TO-92_Inline_Wide
Q3, Q5, Q6, Q7: BC337-25; TO-92_Inline_Wide
Q8: BC327-16; TO-92_Inline_Wide
R1: 825R; R_Axial_DIN0207_L6.3mm_D2.5mm_P10.16mm_Horizontal
R2: 1k65; R_Axial_DIN0207_L6.3mm_D2.5mm_P10.16mm_Horizontal
R3: 3k32; R_Axial_DIN0207_L6.3mm_D2.5mm_P10.16mm_Horizontal
R4: 6k65; R_Axial_DIN0207_L6.3mm_D2.5mm_P10.16mm_Horizontal
R5: 13k3; R_Axial_DIN0207_L6.3mm_D2.5mm_P10.16mm_Horizontal
R6: 7k15; R_Axial_DIN0207_L6.3mm_D2.5mm_P10.16mm_Horizontal
R7: 3k57; R_Axial_DIN0207_L6.3mm_D2.5mm_P10.16mm_Horizontal
R8: 1k78; R_Axial_DIN0207_L6.3mm_D2.5mm_P10.16mm_Horizontal
R9: 887R; R_Axial_DIN0207_L6.3mm_D2.5mm_P10.16mm_Horizontal
R10: 64k9; R_Axial_DIN0207_L6.3mm_D2.5mm_P12.70mm_Horizontal
R11: 1k00; R_Axial_DIN0207_L6.3mm_D2.5mm_P17.78mm_Horizontal
R12: 35k7; R_Axial_DIN0207_L6.3mm_D2.5mm_P10.16mm_Horizontal
R13, R16: 470k; R_Axial_DIN0207_L6.3mm_D2.5mm_P10.16mm_Horizontal
R14: 16k2; R_Axial_DIN0207_L6.3mm_D2.5mm_P10.16mm_Horizontal
R15: 43k2; R_Axial_DIN0207_L6.3mm_D2.5mm_P10.16mm_Horizontal
R17: 4k75; R_Axial_DIN0207_L6.3mm_D2.5mm_P10.16mm_Horizontal
R18: 750R; R_Axial_DIN0207_L6.3mm_D2.5mm_P12.70mm_Horizontal
R19, R40: 51k0; R_Axial_DIN0207_L6.3mm_D2.5mm_P10.16mm_Horizontal
R20: 24k9; R_Axial_DIN0207_L6.3mm_D2.5mm_P15.24mm_Horizontal
R21: 66R5; R_Axial_DIN0207_L6.3mm_D2.5mm_P10.16mm_Horizontal
R22: 56k2; R_Axial_DIN0207_L6.3mm_D2.5mm_P10.16mm_Horizontal
R23: 12k1; R_Axial_DIN0207_L6.3mm_D2.5mm_P10.16mm_Horizontal
R24: 2k70; R_Axial_DIN0207_L6.3mm_D2.5mm_P10.16mm_Horizontal
R25: 10k0; R_Axial_DIN0207_L6.3mm_D2.5mm_P10.16mm_Horizontal
R26: 16k0; R_Axial_DIN0207_L6.3mm_D2.5mm_P20.32mm_Horizontal
R27: 75R0; R_Axial_DIN0207_L6.3mm_D2.5mm_P12.70mm_Horizontal
R28: 16k0; R_Axial_DIN0207_L6.3mm_D2.5mm_P10.16mm_Horizontal
R29: 5k60; R_Axial_DIN0207_L6.3mm_D2.5mm_P10.16mm_Horizontal
R30, R31, R32, R33, R34, R35: 160R; R_Axial_DIN0207_L6.3mm_D2.5mm_P10.16mm_Horizontal
R36, R37, R38: 160R; R_Axial_DIN0207_L6.3mm_D2.5mm_P15.24mm_Horizontal
R39: 1k00; R_Axial_DIN0207_L6.3mm_D2.5mm_P12.70mm_Horizontal
R41: 12R0; R_Axial_DIN0414_L11.9mm_D4.5mm_P22.86mm_Horizontal
R42: 75R0; R_Axial_DIN0309_L9.0mm_D3.2mm_P15.24mm_Horizontal
R43: 1k30; R_Axial_DIN0207_L6.3mm_D2.5mm_P10.16mm_Horizontal
R44: 390R; R_Axial_DIN0309_L9.0mm_D3.2mm_P15.24mm_Horizontal
R45: 4k70; R_Axial_DIN0207_L6.3mm_D2.5mm_P10.16mm_Horizontal
R46: 10R; R_Axial_DIN0207_L6.3mm_D2.5mm_P10.16mm_Horizontal
R47, R48: 470R; R_Axial_DIN0309_L9.0mm_D3.2mm_P15.24mm_Horizontal
R100, R101, R106: 0R; Wire_Bridge_P15.24mm
R102, R107: 0R; Wire_Bridge_P12.70mm
R103, R108: 0R; Wire_Bridge_P10.16mm
R104: 0R; Wire_Bridge_P22.86mm
R105, R112, R113: 0R; Wire_Bridge_P7.62mm
R109, R110: 0R; Wire_Bridge_P17.78mm
R111: 0R; Wire_Bridge_P20.32mm
U1: ITT SAF MCU; DIP-40_W15.24mm
U2: LM2901; DIP-14_W7.62mm
Y1: Crystal; Crystal_C38-LF_D3.0mm_L8.0mm_Horizontal

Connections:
unnamed: BT1.2 (N2), JP10.2 (B), JP11.2 (B)
unnamed: BT1.3 (P1), C10.1, Q3.3 (E), R15.1, R19.2, R103.1, R103.2, U1.1, U1.12, U2.6 (-)
unnamed: BT2.2 (N2), R16.1, R21.2, U1.25
unnamed: BT2.3 (P1), JP10.1 (A), JP11.1 (A)
unnamed: C5.1, R29.2
unnamed: C6.1, J2.19 (Pads), R44.1, R45.1, R110.1, R110.2
unnamed: C7.1, R43.1, R108.1, R108.2, U1.40
unnamed: D1.2 (A), D11.2 (A), K1.1 (COIL_1), Q1.1 (C)
unnamed: D1.1 (K), R10.2, R20.1
unnamed: C1.1, C2.1, C3.1, C4.1, C7.2, C8.1, C9.2, C10.2, C11.2, D2.2 (A), D4.2 (A), J2.1 (Term._31), Q1.3 (E), Q2.1 (C), Q4.3 (E), Q5.3 (E), Q6.3 (E), R12.2, R22.2, R28.1, R45.2, R109.1, R109.2, R112.1, R112.2, U1.21, U2.12 (V-)
unnamed: D2.1 (K), D3.1 (K)
unnamed: D3.2 (A), JP4.2 (B), R6.1, R24.2, R101.1, R101.2
unnamed: D4.1 (K), R39.2, U1.37
unnamed: D5.2 (A), D8.1 (K), R41.2
unnamed: D5.1 (K), D6.1 (K), R27.1
unnamed: C4.2, D6.2 (A), J2.13 (Term._30)
unnamed: D7.2 (A), D9.2 (A), J2.12 (Term._50)
unnamed: D7.1 (K), R39.1
unnamed: C12.2, D9.1 (K), Q8.1 (C), R46.2
unnamed: C6.2, C8.2, C12.1, D8.2 (A), D10.2 (A), J2.7 (Term._15), R47.1, R48.1
unnamed: D10.1 (K), Q8.3 (E)
unnamed: C11.1, D11.1 (K), J1.1 (GND_BULB), K1.2 (COIL_2), R41.1, R42.2
unnamed: J1.12 (BULB_INSPECTION), Q6.1 (C)
unnamed: J1.13 (BULB_OILSERVICE), Q5.1 (C)
unnamed: J1.2 (GND_LED), Q7.3 (E)
unnamed: J1.11 (LED_G1), R36.1
unnamed: J1.10 (LED_G2), R37.1
unnamed: J1.9 (LED_G3), R38.1
unnamed: J1.8 (LED_G4), R35.1
unnamed: J1.7 (LED_G5), R34.1
unnamed: J1.5 (LED_R1), R32.1
unnamed: J1.4 (LED_R2), R31.1
unnamed: J1.3 (LED_R3), R30.1
unnamed: J1.6 (LED_Y), R33.1
unnamed: J2.17 (4/6_cyl.), R40.2, U1.32
unnamed: J2.14 (5V), JP5.1 (A), Q7.2 (B), R5.2, R17.1, R18.1, R26.1, R40.1, R102.1, R102.2, R111.1, R111.2
unnamed: J2.15 (Distance_pulse), U1.30
unnamed: J2.2 (Pad_wear_ind.), R46.1
unnamed: J2.4 (Pads), R47.2, R48.2
unnamed: J2.5 (SI_reset), R43.2
unnamed: C5.2, J2.16 (Speed_pulse)
unnamed: J2.3 (Temp_gauge), K1.12 (N1), R113.1, R113.2
unnamed: J2.6 (Temp_transm.), K1.6 (COM)
unnamed: JP1.1 (A), R9.2, R23.2, R100.1, R100.2
unnamed: JP1.2 (B), JP2.1 (A), R8.2, R9.1
unnamed: JP2.2 (B), JP3.1 (A), R7.2, R8.1
unnamed: JP3.2 (B), JP4.1 (A), R6.2, R7.1
unnamed: JP5.2 (B), JP6.1 (A), R4.2, R5.1
unnamed: JP6.2 (B), JP7.1 (A), R3.2, R4.1
unnamed: JP7.2 (B), JP8.1 (A), R2.2, R3.1
unnamed: JP8.2 (B), JP9.1 (A), R1.2, R2.1
unnamed: JP9.2 (B), R1.1, R10.1
unnamed: K1.11 (N0), R11.1
unnamed: Q1.2 (B), R104.1, R104.2, U1.39
unnamed: Q2.2 (B), R19.1, U1.5
unnamed: Q2.3 (E), R21.1
unnamed: C3.2, Q3.2 (B), R25.1, U2.1
unnamed: C9.1, Q3.1 (C), R24.1, R25.2, R27.2, R107.1, R107.2, U2.3 (V+)
unnamed: Q4.2 (B), R28.2, R29.1
unnamed: Q4.1 (C), R26.2, R106.1, R106.2, U1.34
unnamed: Q5.2 (B), U1.14
unnamed: Q6.2 (B), U1.13
unnamed: Q7.1 (C), R42.1
unnamed: Q8.2 (B), R44.2
unnamed: R13.2, U1.3, U2.14
unnamed: R18.2, U1.36
unnamed: R30.2, U1.15
unnamed: R31.2, U1.16
unnamed: R32.2, U1.17
unnamed: R33.2, U1.18
unnamed: R34.2, U1.19
unnamed: R35.2, U1.20
unnamed: R36.2, U1.24
unnamed: R37.2, U1.23
unnamed: R38.2, U1.22
unnamed: U1.4, U2.13
unnamed: U1.6, Y1.2
unnamed: U1.7, Y1.1
unnamed: U1.35, U2.2
unnamed: C2.2, R20.2, R105.1, R105.2, U1.38, U2.5 (+)
unnamed: C1.2, R11.2, R17.2, U2.4 (-)
unnamed: R22.1, R23.1, U2.7 (+)
unnamed: R16.2, U2.8 (-), U2.11 (+)
unnamed: R12.1, R14.2, U2.10 (-)
unnamed: R13.1, R14.1, R15.2, U2.9 (+)

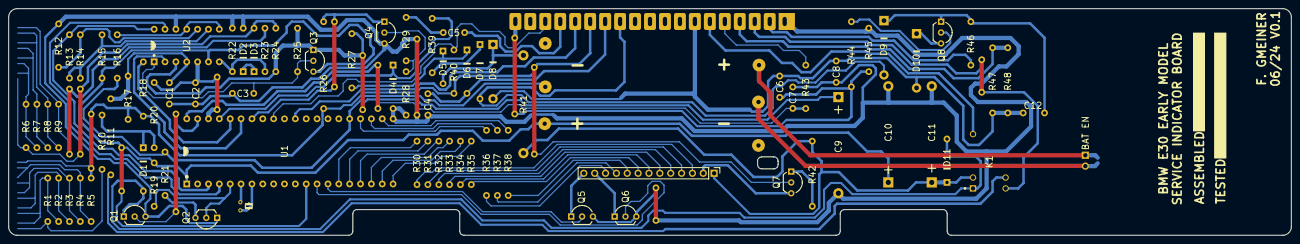
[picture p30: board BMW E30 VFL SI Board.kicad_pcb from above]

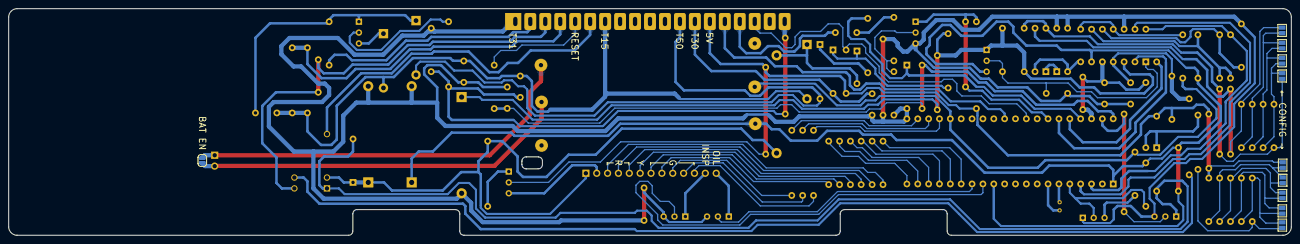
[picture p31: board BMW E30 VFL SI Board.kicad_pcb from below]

Board: 2 copper layers, 300.0 x 53.0 mm, 112 parts (10 on the bottom side), 85 nets.

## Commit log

2024-06-17 Bugfixing of component designators
    [BMW_E30_VFL_SI_Board_Comparator_Circuit.kicad_sch, BMW_E30_VFL_SI_Board_Indicator_Lights.kicad_sch, BMW_E30_VFL_SI_Board_Pad_Wear_Indicator.kicad_sch]
2024-06-19 Added LED board schematics with LEDs instead of Bulbs
2024-06-19 Bundle schematics in folder
2024-06-24 Moved connectur up 2.5mm to correct board fitment
    [BMW E30 VFL SI Indicator-B_Cu.gbr, BMW E30 VFL SI Indicator-B_Mask.gbr, BMW E30 VFL SI Indicator-B_Silks.gbr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]
2024-06-24 Moved connector up 2.5mm to correct board fitment
    [BMW_E30_VFL_SI_Indicator_LED-B_Cu.gbr, BMW_E30_VFL_SI_Indicator_LED-B_Mask.gbr, BMW_E30_VFL_SI_Indicator_LED-B_Silks.gbr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]
2024-06-24 Facelift version inficator board, 7 LEDs (1 Red)
    [BMW E30 NFL SI Indicator LED-B_Cu.gbr, BMW E30 NFL SI Indicator LED-B_Mask.gbr, BMW E30 NFL SI Indicator LED-B_Silks.gbr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]
2024-06-24 Added step files to 3d print the LED holders
    Tested with JLCPCBs resin printing standard "LEDO" resin, fitment is perfect
    [LED_Holder_NFL.stp, LED_Holder_VFL.stp]
2024-06-24 Updated assembly status
2024-06-24 Assembly images
2024-07-02 Updated testing report for battery charging
2024-07-13 Updated Resistor Values from 160 to 510 Ohm
2024-07-13 Updated resistor values
    [BMW E30 NFL SI Indicator LED.kicad_sch]
2024-07-13 Added BOM for Indicator Boards
    [BOM_SI_Board_Indicator_VFL+NFL.xlsx]
2024-07-18 Added V3 with update to CR123 Lithium Battery
    Copy of the addon circuit that BMW used in the later boards and the "converted" boards with the little addon PCB. Uses a single CR123 3V lithium battery. This has a capacity of ~1600mAh compared to the combined 1900mAh of the original CR14250. The board uses Keystone 54 battery clips so the battery can be replaced without soldering.
    [BMW E30 VFL SI Board V3-B_Cu.gbr, BMW E30 VFL SI Board V3-B_Mask.gbr, BMW E30 VFL SI Board V3-B_Silks.gbr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]
2024-07-18 Updated for Lithium-Battery V3
    [BOM_SI_Board_Reman.xlsx]
2024-08-18 Printable bending guide for resistors and diodes
2024-08-18 Added Mouser Part Nrs + Bending Pitch
    [BOM_SI_Board_Reman.xlsx]
2024-08-23 Increase mounting hole diameter to 6.5mm
    [BMW_E30_VFL_SI_Indicator_LED-B_Cu.gbr, BMW_E30_VFL_SI_Indicator_LED-B_Mask.gbr, BMW_E30_VFL_SI_Indicator_LED-B_Silks.gbr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]
